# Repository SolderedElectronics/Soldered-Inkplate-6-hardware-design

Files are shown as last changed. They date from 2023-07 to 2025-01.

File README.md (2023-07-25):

# Inkplate 6 v2 Hardware design

## About the product

| Inkplate 6 v2 |
| :----------------------------------------------------------: |
|      [Buy Inkplate 6 v2](https://www.solde.red/333062)      |

If you’re like us, the first time you saw an e-reader, you thought to yourself, "I could do something with that." Thanks to clean lines, high contrast, daylight readability, and the remarkable level of energy efficiency that comes from drawing power only when changing the contents of the screen, e-paper is uniquely suited to many applications. With Inkplate 6, our goal is to make e-paper accessible to hobbyists and DIY product designers by offering a plug-and-play hardware platform that is super-easy to use and compatible with Arduino.

To name a few features, Inkplate 6 has stunning 6 inch e-paper display with refresh rate of 1.26s, with partial update 264ms, greyscale mode and partial updates support. Powered by ESP32, you will have strong microcontroller with WiFi and Bluetooth on your disposal. Using our Arduino library, it's 5 minute work to get the board running for you. It's 100% open-source for both software and hardware, so it's OSHWA certified. What is especially interesting is that Inkplate uses recycled screens taken from old e-book readers, which is very environmentally friendly, but you have to keep in mind that some screens may have small scratches because of this. All screens with large scratches and damages are not used at all.

## Repository contents

All Soldered Electronics hardware designed in KiCAD, and repositories are organized in the following way:

- CAD folder - contains KiCAD files (Schematics, Board, Panel Board), sorted by version. Change log lists all changes between versions.
- OUTPUTS - contains useful files, such as Bill of Materials (BOM), PDF of schematics, 3D .step file of the board and gerber files, sorted by version. 
- OUTPUTS -> Compliance - Certificates and useful legal stuff. 

## Want to contribute?

Please feel free to submit a pull request if you have any contributions. We encourage you to submit an issue or pull request if you find a bug. 

## About Soldered

soldered-logo

At Soldered, we design and manufacture a wide selection of electronic products to help you turn your ideas into acts and bring you one step closer to your final project. Our products are intented for makers and crafted in-house by our experienced team in Osijek, Croatia. We believe that sharing is a crucial element for improvement and innovation, and we work hard to stay connected with all our makers regardless of their skill or experience level. Therefore, all our products are open-source. Finally, we always have your back. If you face any problem concerning either your shopping experience or your electronics project, our team will help you deal with it, offering efficient customer service and cost-free technical support anytime. Some of those might be useful for you:

- [Web Store](https://www.soldered.com/shop)
- [Tutorials & Projects](https://soldered.com/learn)
- [Community & Technical support](https://soldered.com/community)

## License info

All Soldered open-source hardware (OSH) is under The TAPR Open Hardware License. Read more in the LICENSE file. 

No warranty - all designs in this repository are distributed in the hope that they will be useful, but without any warranty. They are provided "AS IS", therefore without warranty of any kind, either expressed or implied. The entire quality and performance of what you do with the contents of this repository are your responsibility. In no event, Soldered Electronics will be liable for your damages, losses, including any general, special, incidental or consequential damage arising out of the use or inability to use the contents of this repository. 

## Have fun! 
And thank you from your fellow makers at Soldered Electronics.

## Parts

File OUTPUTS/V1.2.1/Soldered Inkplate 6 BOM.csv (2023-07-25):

Id | Designator | Package | Quantity | Designation | Supplier and ref
1 | SW2 | YTSA007A0151803B | 1 | YTSA007A0151803B
2 | C34,C31,C49,C55,C27,C48,C33,C26,C44,C30,C36,C43,C38,C25,C56,C24,C42 | 0603C | 17 | 100n
3 | C23,C28,C47,C21,C37,C32 | 0603C | 6 | 2u2
4 | R20,R32,R8,R37,R38 | 0603R | 5 | 4k7
5 | L2 | NR4012 | 1 | NR4012T2R2M
6 | K9,K10,K47,K49,K21,K54,K29,K28,K6,K38,K34,K32,K56,K53,K27,K45,K24,K51,K33,K44,K30,K17,K31,K40,K57,K39,K19,K22,K41,K4,K37,K7,K42,K5,K55,K20,K35,K43,K25,K46,K36,K26,K58,K11,K18,K52,K12,K16,K48,K23,K50 | HEADER_MALE_1X1_Inkplate | 51 | HEADER_MALE_1X1_Inkplate
7 | F1 | 1206FUSE | 1 | 1206FUSE-500mA
8 | C6,C3,C4,C53,C54,C13,C12,C52,C2,C39,C51,C1,C9,C45,C11,C7 | 0805C | 16 | 4u7-TMK212AB7475KG-T
9 | R45,R4,R19,R33,R1,R22,R51 | 0603R | 7 | 10k
10 | D9,D6 | SOT-23-3 | 2 | BAT54S
11 | D1,D3 | SOD-323-2 | 2 | CUS10F30,H3F
12 | D10,D11 | M4_DIODA | 2 | M4_DIODA
13 | U6 | SOT-23-5 | 1 | TPS3840PL27DBVR
14 | U3 | TPS7A2633DRVR | 1 | TPS7A2633DRVR
15 | PAD2,PAD5,PAD6,PAD7,PAD1,PAD4,PAD3 | PAD_4x4 | 7 | PAD_4x4
16 | X1 | ABS07AIG-32.768KHZ-7-D-T | 1 | 7LC32768F12UC
17 | R16,R25,R5,R17,R43,R26,R6,R47,R7,R44,R49,R48,R31,R15 | 0603R | 14 | 100k
18 | L1 | 1515L | 1 | LQH44PN4R7MP0L
19 | R10 | 0603R | 1 | 2k49
20 | SW1,SW3 | K2-1114SA-A4SW-06 | 2 | K2-1114SA-A4SW-06
21 | U10 | PCF85063A | 1 | PCF85063A
22 | R50 | 0603R | 1 | 330R
23 | R36,R35,R14,R21,R23,R27,R24,R9,R34 | 0603R | 9 | 1k
24 | U12 | ESP32-WROVER | 1 | ESP32-WROVER
25 | K1 | INKPLATE TEST HEADER | 1 | Inkplate_TP
26 | C8,C5,C10 | 0603C | 3 | 10u-GRM188R61E106KA73J
27 | C20,C50 | 2917C | 2 | DNP
28 | R29,R18 | 0603R | 2 | DNP
29 | C41,C40 | 0603C | 2 | DNP
30 | Q10,Q1,Q2 | SOT-23-3 | 3 | PMOS
31 | D2,D12,D5,D4 | SOD-323 | 4 | BAT20J
32 | D7 | 0402LED | 1 | RED
33 | R11 | 0603R | 1 | 510k
34 | U8,U9 | PCAL6416AHF,128 | 2 | PCAL6416AHF,128
35 | Q7,Q5,Q6 | SOT-23-3 | 3 | NPN
36 | C14,C15 | 0603C | 2 | 2u2-GRM188R61E225MA12D
37 | K13 | HYC77-TF09-200 | 1 | HYC77-TF09-200
38 | JP3,JP6,JP4,JP2,JP5 | SMD_JUMPER_3_PAD_CONNECTED_LEFT_TRACE | 5 | SMD_JUMPER_3_PAD_CONNECTED_LEFT_TRACE
39 | K14 | CR2032-BS-6-1 | 1 | CR2032_BS-6-1
40 | R13,R12 | 0603R | 2 | 5k1
41 | C17,C16 | 0603C | 2 | 10n-AC0603KRX7R8BB103
42 | H1,H4,H3,H2 | Standoff_M3 | 4 | Standoff_M3
43 | K8 | easyC-connector | 1 | easyC-SMD
44 | U1 | VQFN-49 | 1 | TPS65186RGZ
45 | D8 | LTST-S270GKT | 1 | 0603LED_SIDE
46 | K15 | AXT334124 | 1 | AXT334124
47 | Q3 | SOT-23-3 | 1 | NMOS
48 | R41,R39 | 0603R | 2 | 1M
49 | C35 | 0603C | 1 | 100p
50 | R2 | 0603R | 1 | NTC-NCP18XH103F03RB
51 | R28 | 0603R | 1 | 0R
52 | JP1 | SMD_JUMPER | 1 | SMD_JUMPER
53 | C46,C22,C29 | 1206C | 3 | 10u
54 | S1 | SK-3296S-01-L1 | 1 | SK-3296S-01-L1
55 | K2 | JST-2pin-SMD | 1 | JST-2pin-SMD
56 | R40 | 0603R | 1 | 47k5-RC0603FR-0747K5L
57 | R3 | 0603R | 1 | 43k-RC0603FR-0743KL
58 | C19,C18 | 0603C | 2 | 100n-AC0603KRX7R8BB104
59 | R46 | 0603R | 1 | 47k
60 | U5 | SOP-16 | 1 | CH340C
61 | R42 | 0603R | 1 | 52k3-RC0603FR-0752K3L
62 | R30 | 0603R | 1 | 47R
63 | Q9 | SOT-23-3 | 1 | DNP
64 | Q8,Q4 | SOT-23-3 | 2 | SSM3J358R,LF
65 | U2 | SOT-23-5 | 1 | MCP73831T
66 | U7 | SN74LVC1G34DBV | 1 | SN74LVC1G34DBV
67 | U4 | TSSOP-14 | 1 | MC14093BDTR2G
68 | K3 | U262-161N-4BVC11 | 1 | U262-161N-4BVC11
69 | U11 | ED060SC7 | 1 | ED060SC7

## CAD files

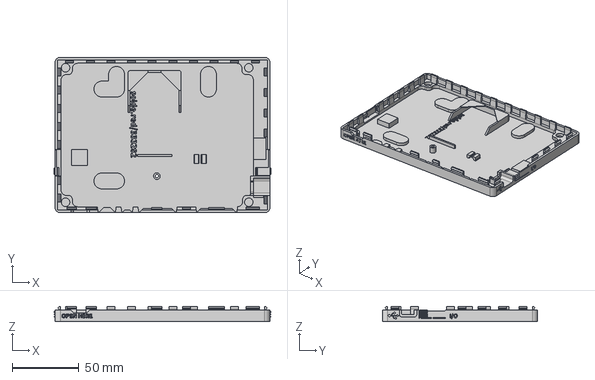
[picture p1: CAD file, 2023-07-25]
CAD/V1.2.1/Source 3D files/Soldered Inkplate 6 v1.2.0. Bottom v1.1.2..step
163.0 x 116.8 x 11.3 mm

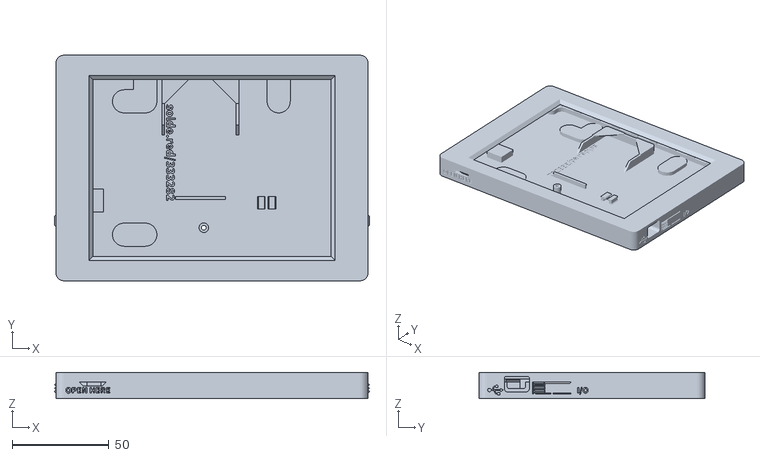
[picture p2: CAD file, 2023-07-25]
OUTPUTS/V1.2.1/3D printable files/Soldered Inkplate 6 v1.2.0. Case.stl
163.0 x 116.8 x 13.5

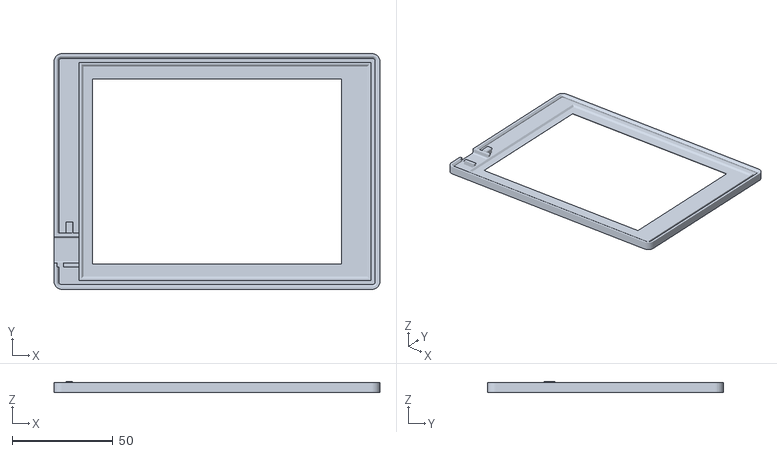
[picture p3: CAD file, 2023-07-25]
OUTPUTS/V1.2.1/3D printable files/Soldered Inkplate 6 v1.2.0. Top v 1.1.2..stl
161.4 x 116.8 x 5.60

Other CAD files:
CAD/V1.2.1/Source 3D files/Soldered Inkplate 6 v1.2.0. Case.step
CAD/V1.2.1/Source 3D files/Soldered Inkplate 6 v1.2.0. Top v 1.1.2..step
OUTPUTS/V1.2.1/3D printable files/Soldered Inkplate 6 v1.2.0. Bottom v1.1.2..stl
CAD/V1.2.0/Source 3D files/Soldered Inkplate 6 v1.2.0. Top v 1.1.2..step
CAD/V1.2.0/Source 3D files/Soldered Inkplate 6 v1.2.0. Case.step
OUTPUTS/V1.2.0/3D printable files/Soldered Inkplate 6 v1.2.0. Bottom v1.1.2..stl
CAD/V1.2.0/Source 3D files/Soldered Inkplate 6 v1.2.0. Bottom v1.1.2..f3d
CAD/V1.2.0/Source 3D files/Soldered Inkplate 6 v1.2.0. Case.f3z
CAD/V1.2.0/Source 3D files/Soldered Inkplate 6 v1.2.0. Top v 1.1.2..f3d
CAD/V1.2.1/Source 3D files/Soldered Inkplate 6 v1.2.0. Bottom v1.1.2..f3d
CAD/V1.2.1/Source 3D files/Soldered Inkplate 6 v1.2.0. Case.f3z
CAD/V1.2.1/Source 3D files/Soldered Inkplate 6 v1.2.0. Top v 1.1.2..f3d

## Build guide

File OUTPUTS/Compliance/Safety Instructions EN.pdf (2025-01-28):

PLEASE RETAIN THIS INFORMATION FOR FUTURE REFERENCE.

BEFORE USING THIS PRODUCT, READ ALL INSTRUCTION IN THIS DOCUMENT.

Product name: Soldered Inkplate 6
Getting started: To get started, please visit www.soldered.com

## WARNINGS

- This product should not be covered and should be operated in well ventilated enviroment.
- The product should be placed on a stable, flat, non-conductive surface and should not be contacted by conductive items.
- Connection of other devices may affect compliance or result in damage to the unit, and invalidate the warranty.
- Where peripherals are connected that do not include the cable or connector, the cable or connector used must offer adequate insulation and operation in order that the requirements of the relevant performance and safety requirements are met.
- There is a danger of explosion if the battery is incorrectly placed.
- The product should not be used outside of its specified working range.

## INSTRUCTIONS FOR SAFE USE

To avoid malfunction or damage to your device, please observe the following:
- Do not expose it to water, moisture or place on a conductive surface when turned on. Do not handle the unit with wet hands.
- Do not expose it to heat from any source; the product is designed to be used at normal ambient room temperatures. The product is intended to be used inside.
- Take care when handling to avoid mechanical or electrical damage to any part of the unit. Avoid handling the unit while it's powered. Use ESD protection.
- Use only supplied cable (or the cable of the same or higher quality) with the unit.

## COMPLIANCE INFORMATION

The product complies with the relevant provision of the RoHS Directive for the European Union. In common with all Electrical and Electronic Equipment (EEE), the product should not be disposed household waste.

ELECTROMAGNETIC COMPABILITY AND OPERATION

- The product is in conformity with the protection requirements of EU Council Directive 2014/30/EU on the laws of the Member States relating of electromagnetic compability, and Electromagnetic Compability Regulations 2016 of the UK.
- WARNING: Please do not alter the design of this product, doing so may void your ability to use the product freely, this includes altering the frequency at which product operates.

### Regulatory Compliance and Important Safety Information

Soldered Electronics d.o.o., Vinkovačka cesta 68, 31000 Osijek, Croatia. VAT ID: HR83200237288

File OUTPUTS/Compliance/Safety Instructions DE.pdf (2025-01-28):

BITTE BEWAHREN SIE DIESE INFORMATIONEN ZUR SPÄTEREN VERWENDUNG AUF.
LESEN SIE VOR DER VERWENDUNG DIESES PRODUKTS ALLE ANWEISUNGEN IN DOKUMENT. Produktname: Soldered Inkplate 6
Die ersten Schritte:Besuchen Sie www.soldered.com, um loszulegen.

## WARNUNGEN

- Dieses Produkt sollte nicht abgedeckt werden und in einer gut belüfteten Umgebung betrieben werden.
- Das Produkt sollte auf einer stabilen, flachen, nicht leitenden Oberfläche aufgestellt werden und nicht mit leitenden Gegenständen in Berührung kommen.
- Der Anschluss anderer Geräte kann die Konformität beeinträchtigen oder zu Schäden am Gerät führen und zum Erlöschen der Garantie führen.
- Wenn Peripheriegeräte angeschlossen werden, die nicht das Kabel oder den Stecker enthalten, muss das verwendete Kabel oder muss das verwendete Kabel bzw. der verwendete Steckverbinder eine angemessene Isolierung und Funktion aufweisen, damit die Anforderungen die einschlägigen Leistungs- und Sicherheitsanforderungen erfüllt werden.
- Es besteht Explosionsgefahr, wenn die Batterie falsch eingesetzt wird.
- Das Produkt sollte nicht außerhalb des angegebenen Arbeitsbereichs verwendet werden.

## HINWEISE ZUR SICHEREN ANWENDUNG

Um Fehlfunktionen oder Schäden an Ihrem Gerät zu vermeiden, beachten Sie bitte die folgenden Hinweise:
- Setzen Sie das Gerät nicht Wasser oder Feuchtigkeit aus und stellen Sie es nicht auf eine
leitende Oberfläche, wenn es eingeschaltet ist. Das Gerät nicht mit nassen Händen anfassen.
- Setzen Sie es keiner Wärmequelle aus; das Produkt ist für die Verwendung bei normalen Raumtemperaturen ausgelegt. Das Produkt ist für die Verwendung in Innenräumen vorgesehen.
- Seien Sie bei der Handhabung vorsichtig, um mechanische oder elektrische Schäden an Teilen des Geräts zu vermeiden. Fassen Sie das Gerät nicht an, wenn es unter Spannung steht. Verwenden Sie einen ESD-Schutz.
- Verwenden Sie nur das mitgelieferte Kabel (oder ein gleich- oder höherwertiges Kabel)
mit dem Gerät.

## COMPLIANCE-INFORMATIONEN

Das Produkt entspricht den entsprechenden Bestimmungen der RoHS-Richtlinie für die Europäische Union. Wie alle elektrischen und elektronischen Geräte (EEE), sollte das Produkt nicht über den Hausmüll entsorgt werden.
ELEKTROMAGNETISCHE VERTRÄGLICHKEIT UND BETRIEB
- Das Produkt entspricht den Schutzanforderungen der Richtlinie des EU-Rates 2014/30/EU über die Rechtsvorschriften der Mitgliedstaaten zur elektromagnetischen Verträglichkeit und den Elektromagnetische Verträglichkeitsverordnung 2016 des Vereinigten Königreichs.
- WARNUNG: Bitte verändern Sie nicht das Design dieses Produkts, da dies dazu führen kann, dass Sie das Produkt nicht mehr uneingeschränkt nutzen können.
Dies gilt auch für die Änderung der Frequenz, mit der das Produkt arbeitet.

## Einhaltung gesetzlicher Vorschriften und wichtige

Soldered Electronics d.o.o., Vinkovačka cesta 68, 31000 Osijek, Croatia. VAT ID: HR83200237288

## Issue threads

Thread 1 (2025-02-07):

Supported Inkplate 6 Versions

itopaloglu83, 2025-02-07:
Hello,

It looks like there are multiple versions of Soldered Inkplate 6. The product link on the readme file points to the retired version. And the inkplate documentation points to another repo with different files. Which versions does this repo support? Also is there a way to determine which exact version we have (v1.2.0 vs v1.2.1)? Thank you.

https://soldered.com/product/inkplate-6-6-e-paper-board/ (SKU: 333232)

https://soldered.com/product/retired-inkplate-6-6-e-paper-board/ (SKU: 333062)
https://github.com/SolderedElectronics/Inkplate-6-hardware (inkplate documentation)

Edit: The SKU number engraved on the STL files says "solde.red/333282".

rsoric, 2025-02-18:
Greetings @itopaloglu83,

sorry for a bit of a late reply, we were busy with some projects.

The e-radionica Inkplates are the older versions (mostly blue PCB) and purple Inkplates are Soldered Inkplates (purple PCB). This difference also has to do with the different GPIO expander on board, check out this page in our documentation: https://inkplate.readthedocs.io/en/latest/arduino.html#io-expander-functions

The retired product you linked is the e-radionica Inkplate 6 (it also has touchpads, this is how I know, the newer version doesn't have those), the non-retired one is the Soldered version. This repository is for the Soldered (non-retired) version.

The battery which fits perfectly in the case is the SKU engraved in the STL, and this is the battery which we ship in the version of our device with battery.

Hope that's useful, all the best
-Rob

Closed 2025-02-18.

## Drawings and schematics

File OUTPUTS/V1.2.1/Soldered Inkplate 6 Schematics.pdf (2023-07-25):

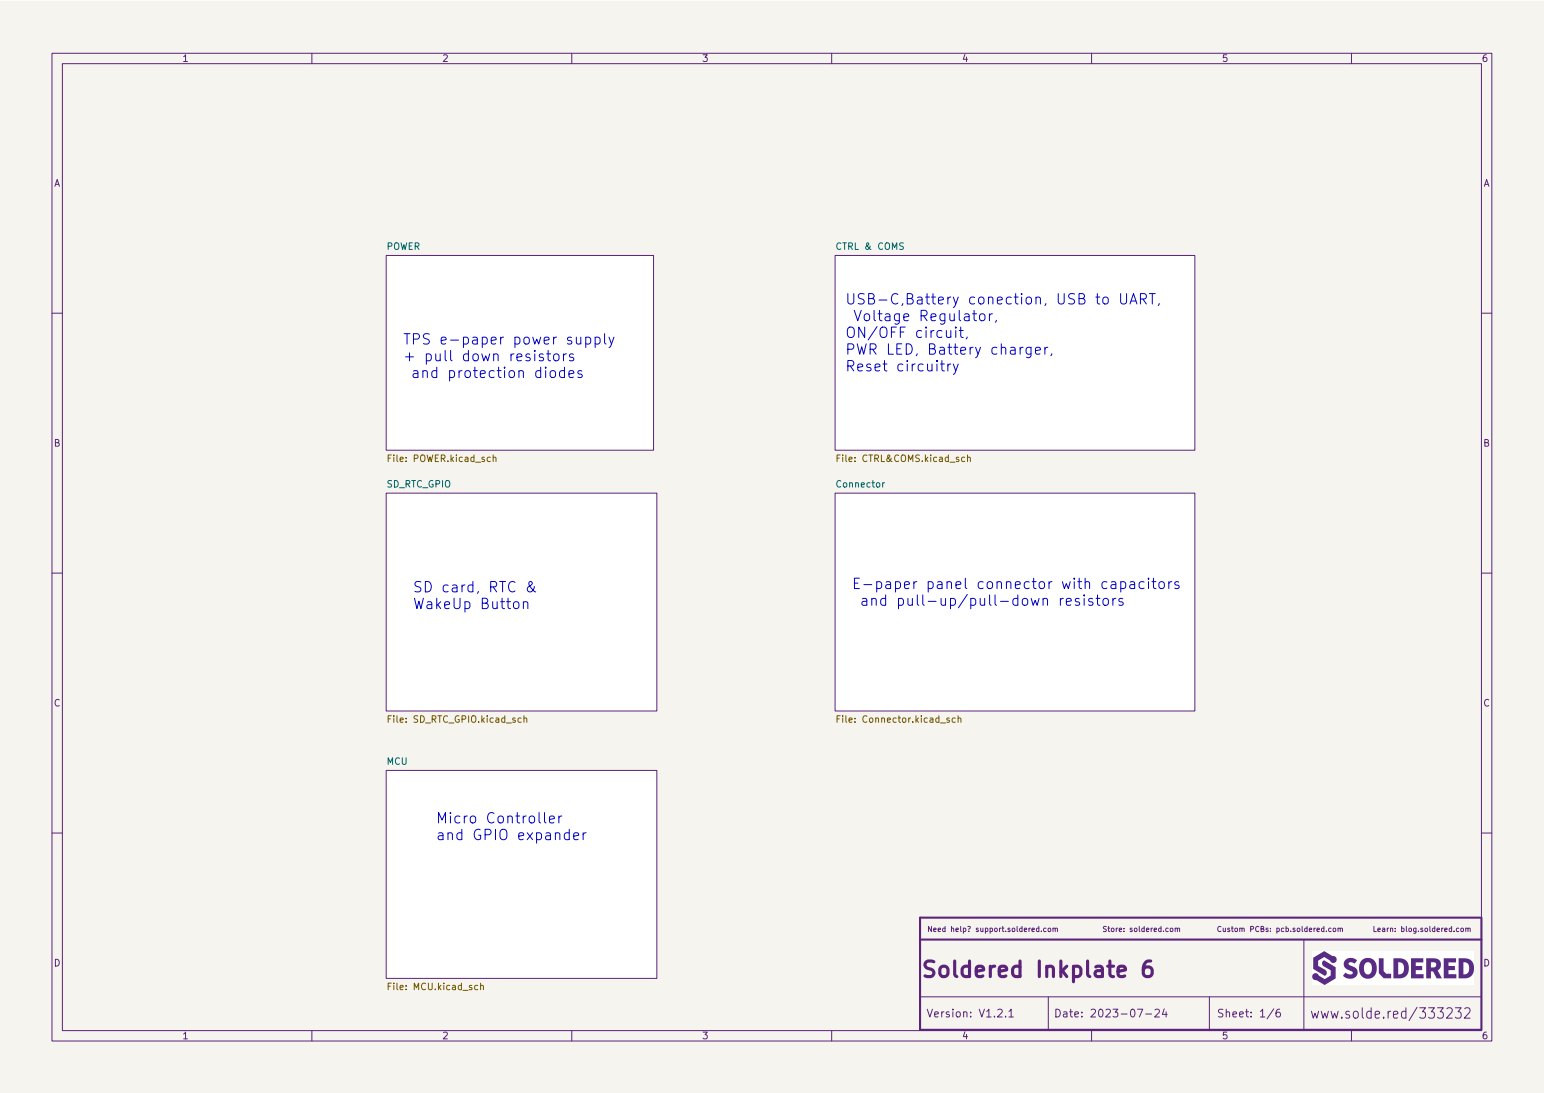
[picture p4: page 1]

Voltage Regulator,
ON/OFF circuit,
PWR LED, Battery charger,
Reset circuitry

TPS e-paper power supply
+ pull down resistors
and protection diodes

File: CTRL&COMS.kicad_sch Connector File: Connector.kicad_sch SD_RTC_GPIO

E-paper panel connector with capacitors
and pull-up/pull-down resistors

Learn: blog.soldered.com

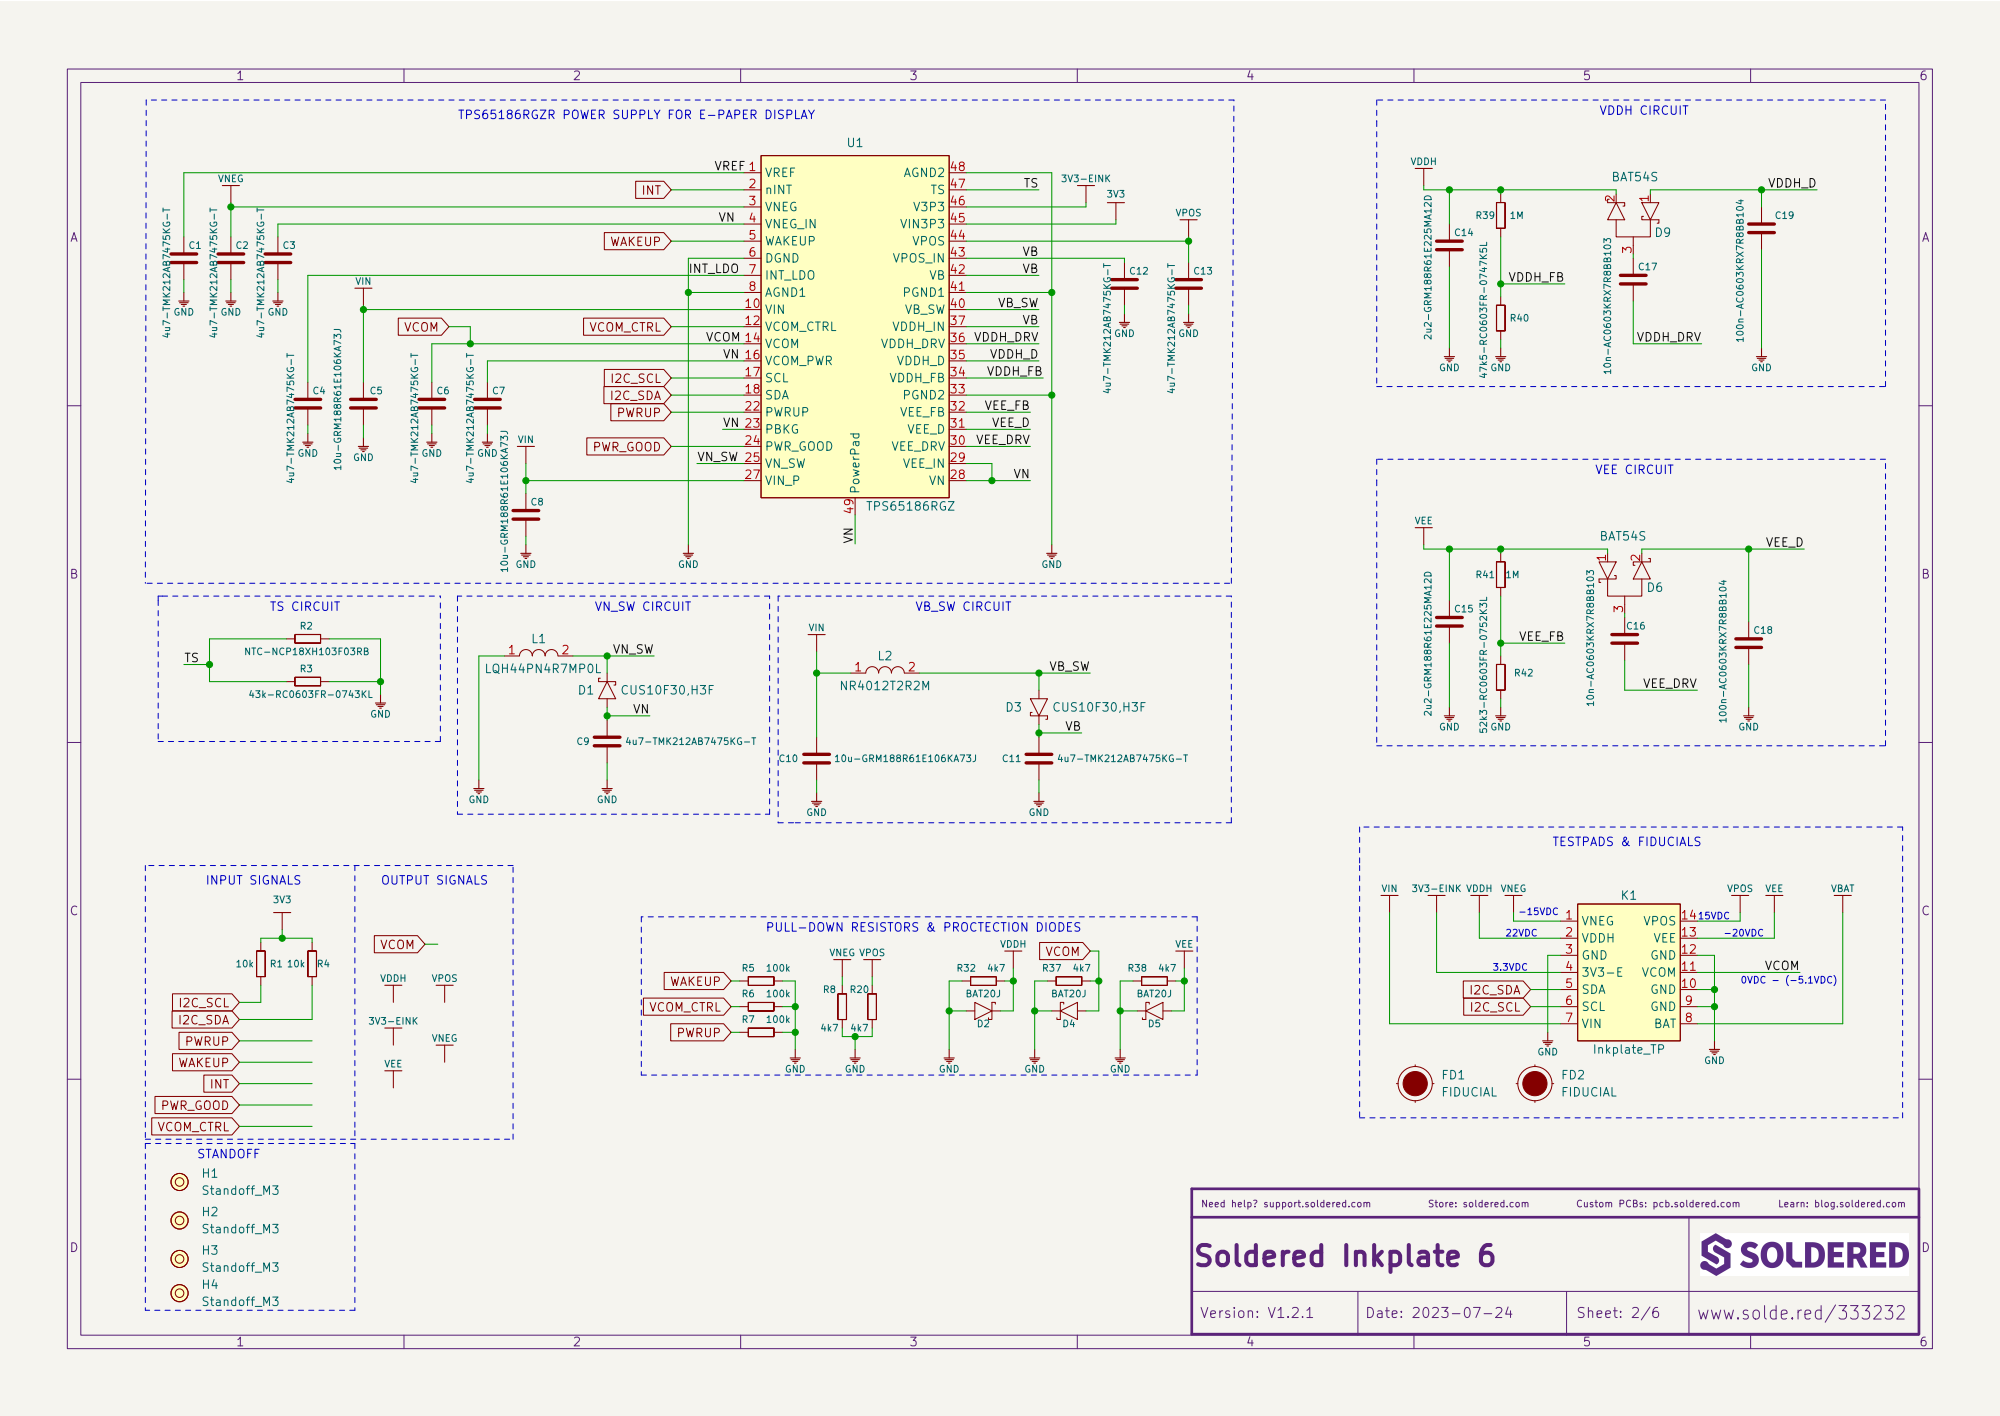
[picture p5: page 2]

TPS65186RGZR POWER SUPPLY FOR E-PAPER DISPLAY

VREF 1 VIN 10 VCOM_CTRL 12 VCOM 14 VCOM_PWR 16 SCL 17 SDA 18

VN | VDDH_D
VN VN_SW | VDDH_FB

0VDC - (-5.1VDC) PULL-DOWN RESISTORS & PROCTECTION DIODES OUTPUT SIGNALS

Learn: blog.soldered.com

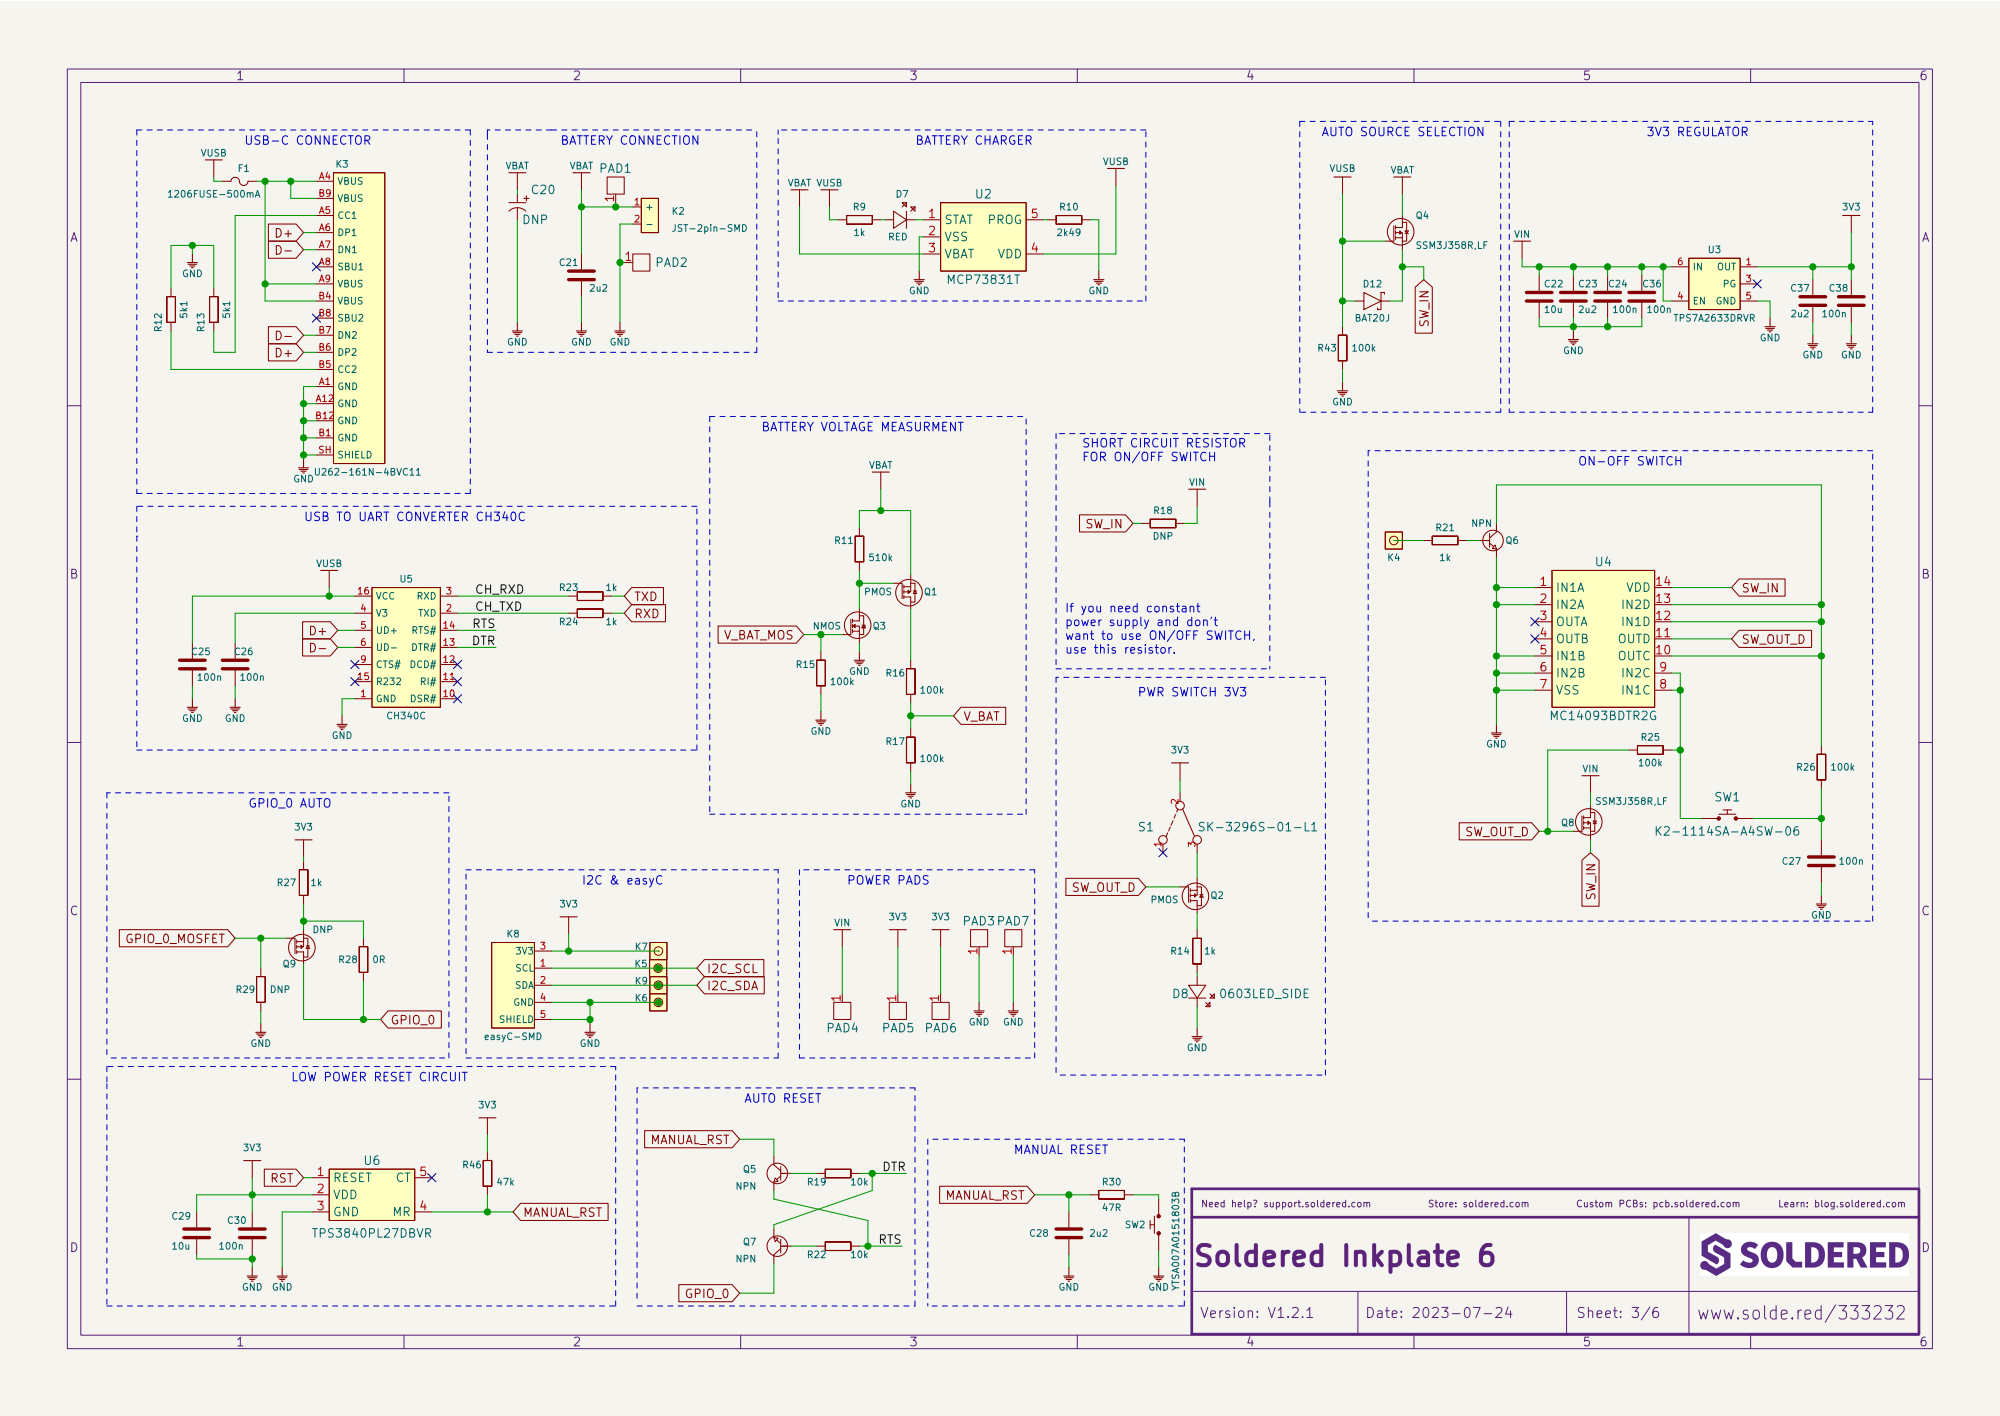
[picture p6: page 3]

BATTERY VOLTAGE MEASURMENT POWER PADS

power supply and don't want to use ON/OFF SWITCH, use this resistor. PWR SWITCH 3V3 SHORT CIRCUIT RESISTOR
FOR ON/OFF SWITCH

USB TO UART CONVERTER CH340C

If you need constant

1 PAD5 Q7 NPNQ5 NPN RESET R19 10k 1 VDD 2 GND 3 MR 4 CT 5 U6 TPS3840PL27DBVR
100n GND

LOW POWER RESET CIRCUIT

Learn: blog.soldered.com

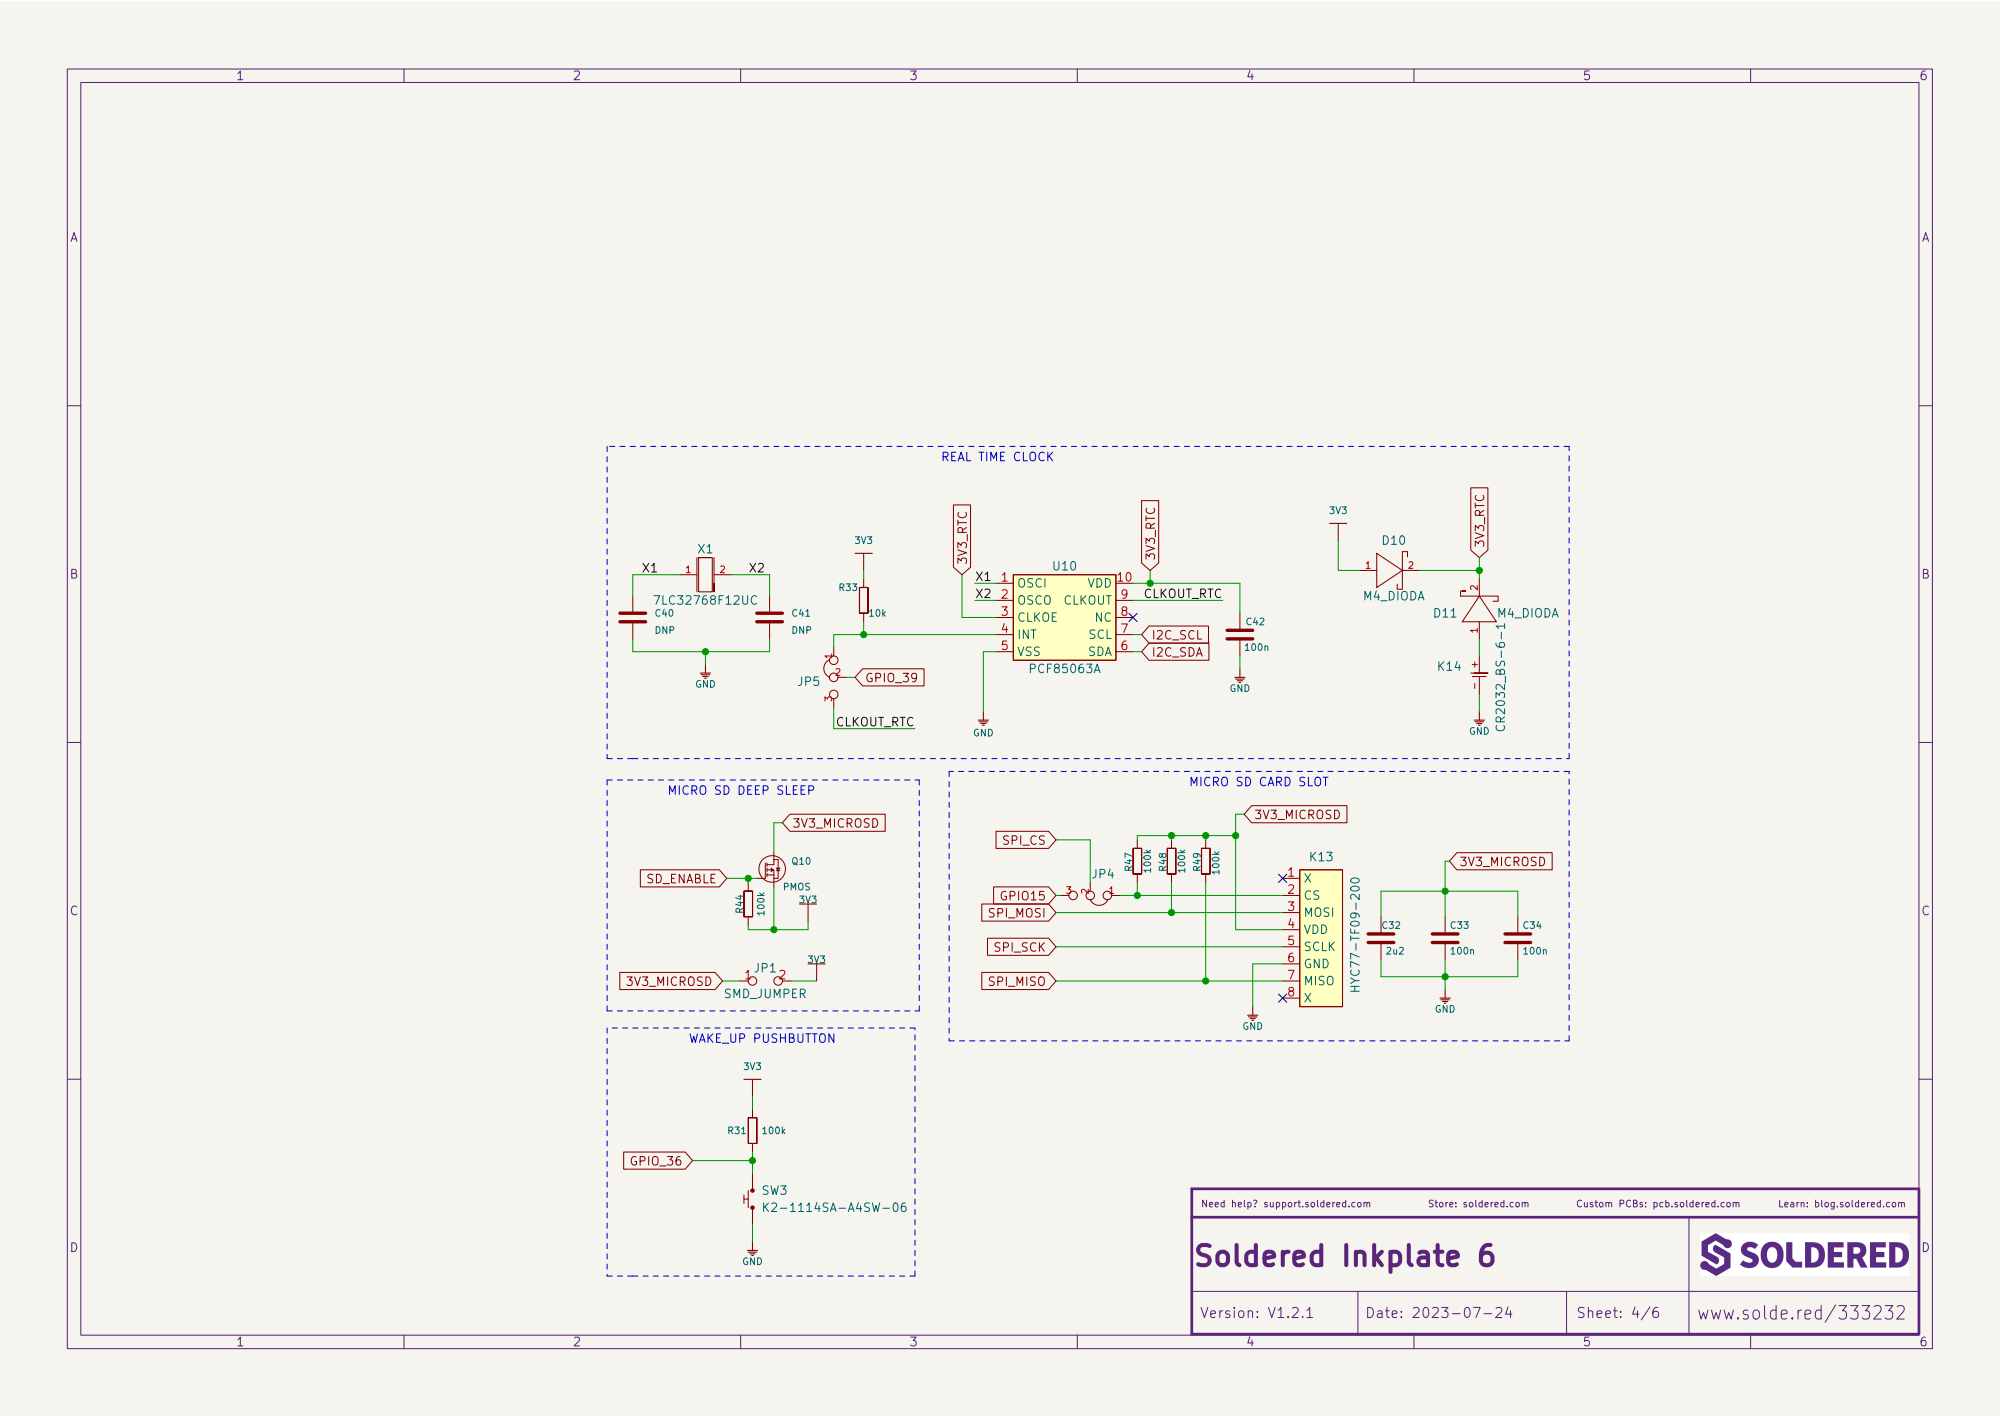
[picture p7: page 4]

Learn: blog.soldered.com

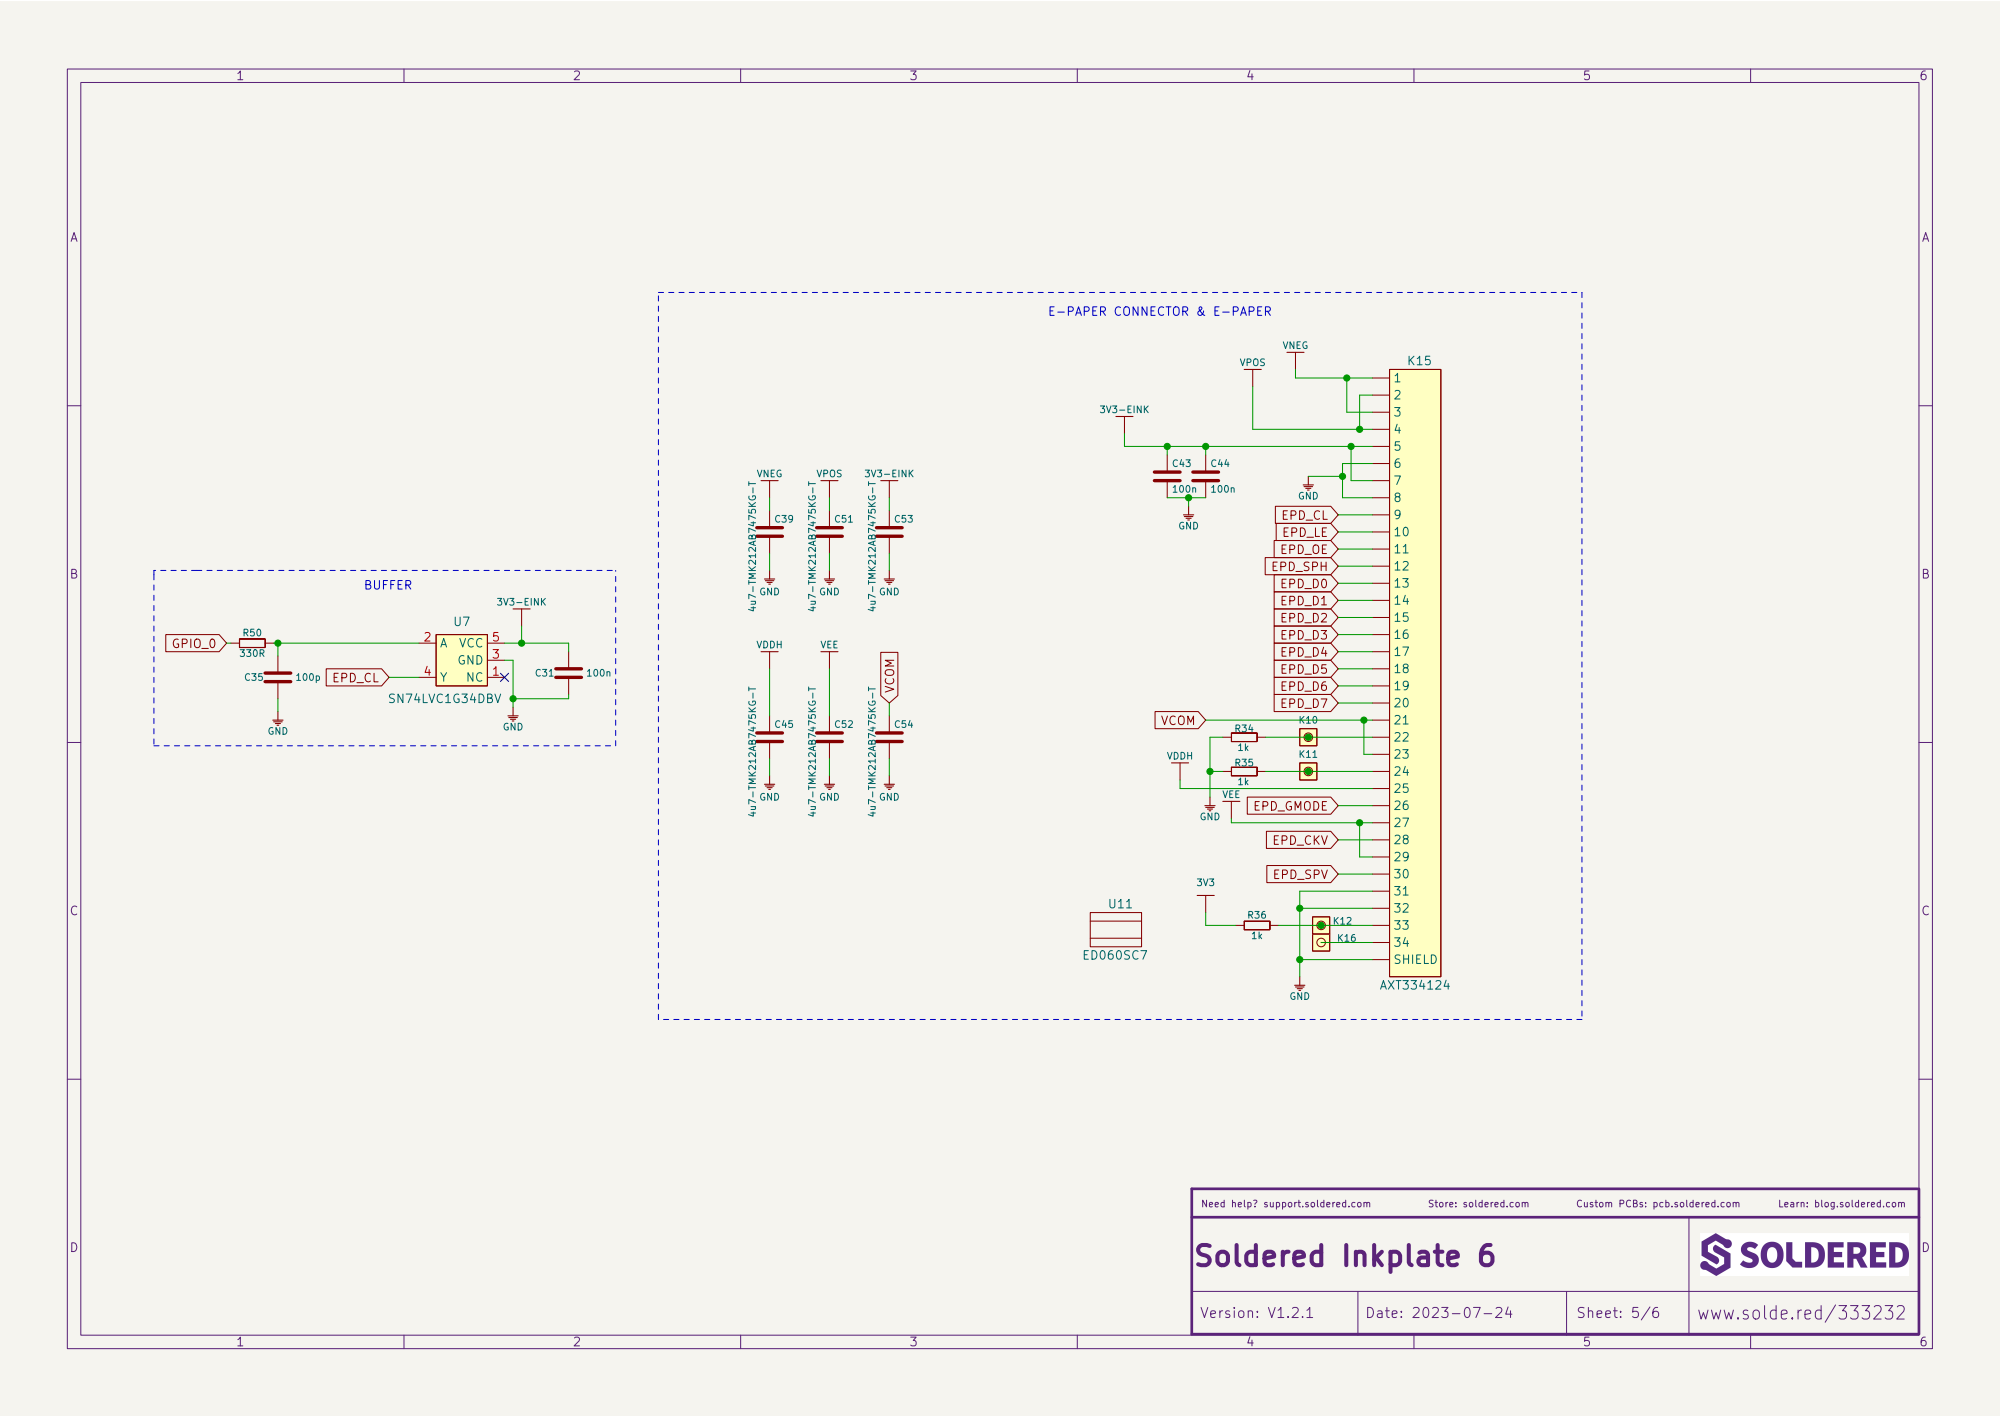
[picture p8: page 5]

Learn: blog.soldered.com

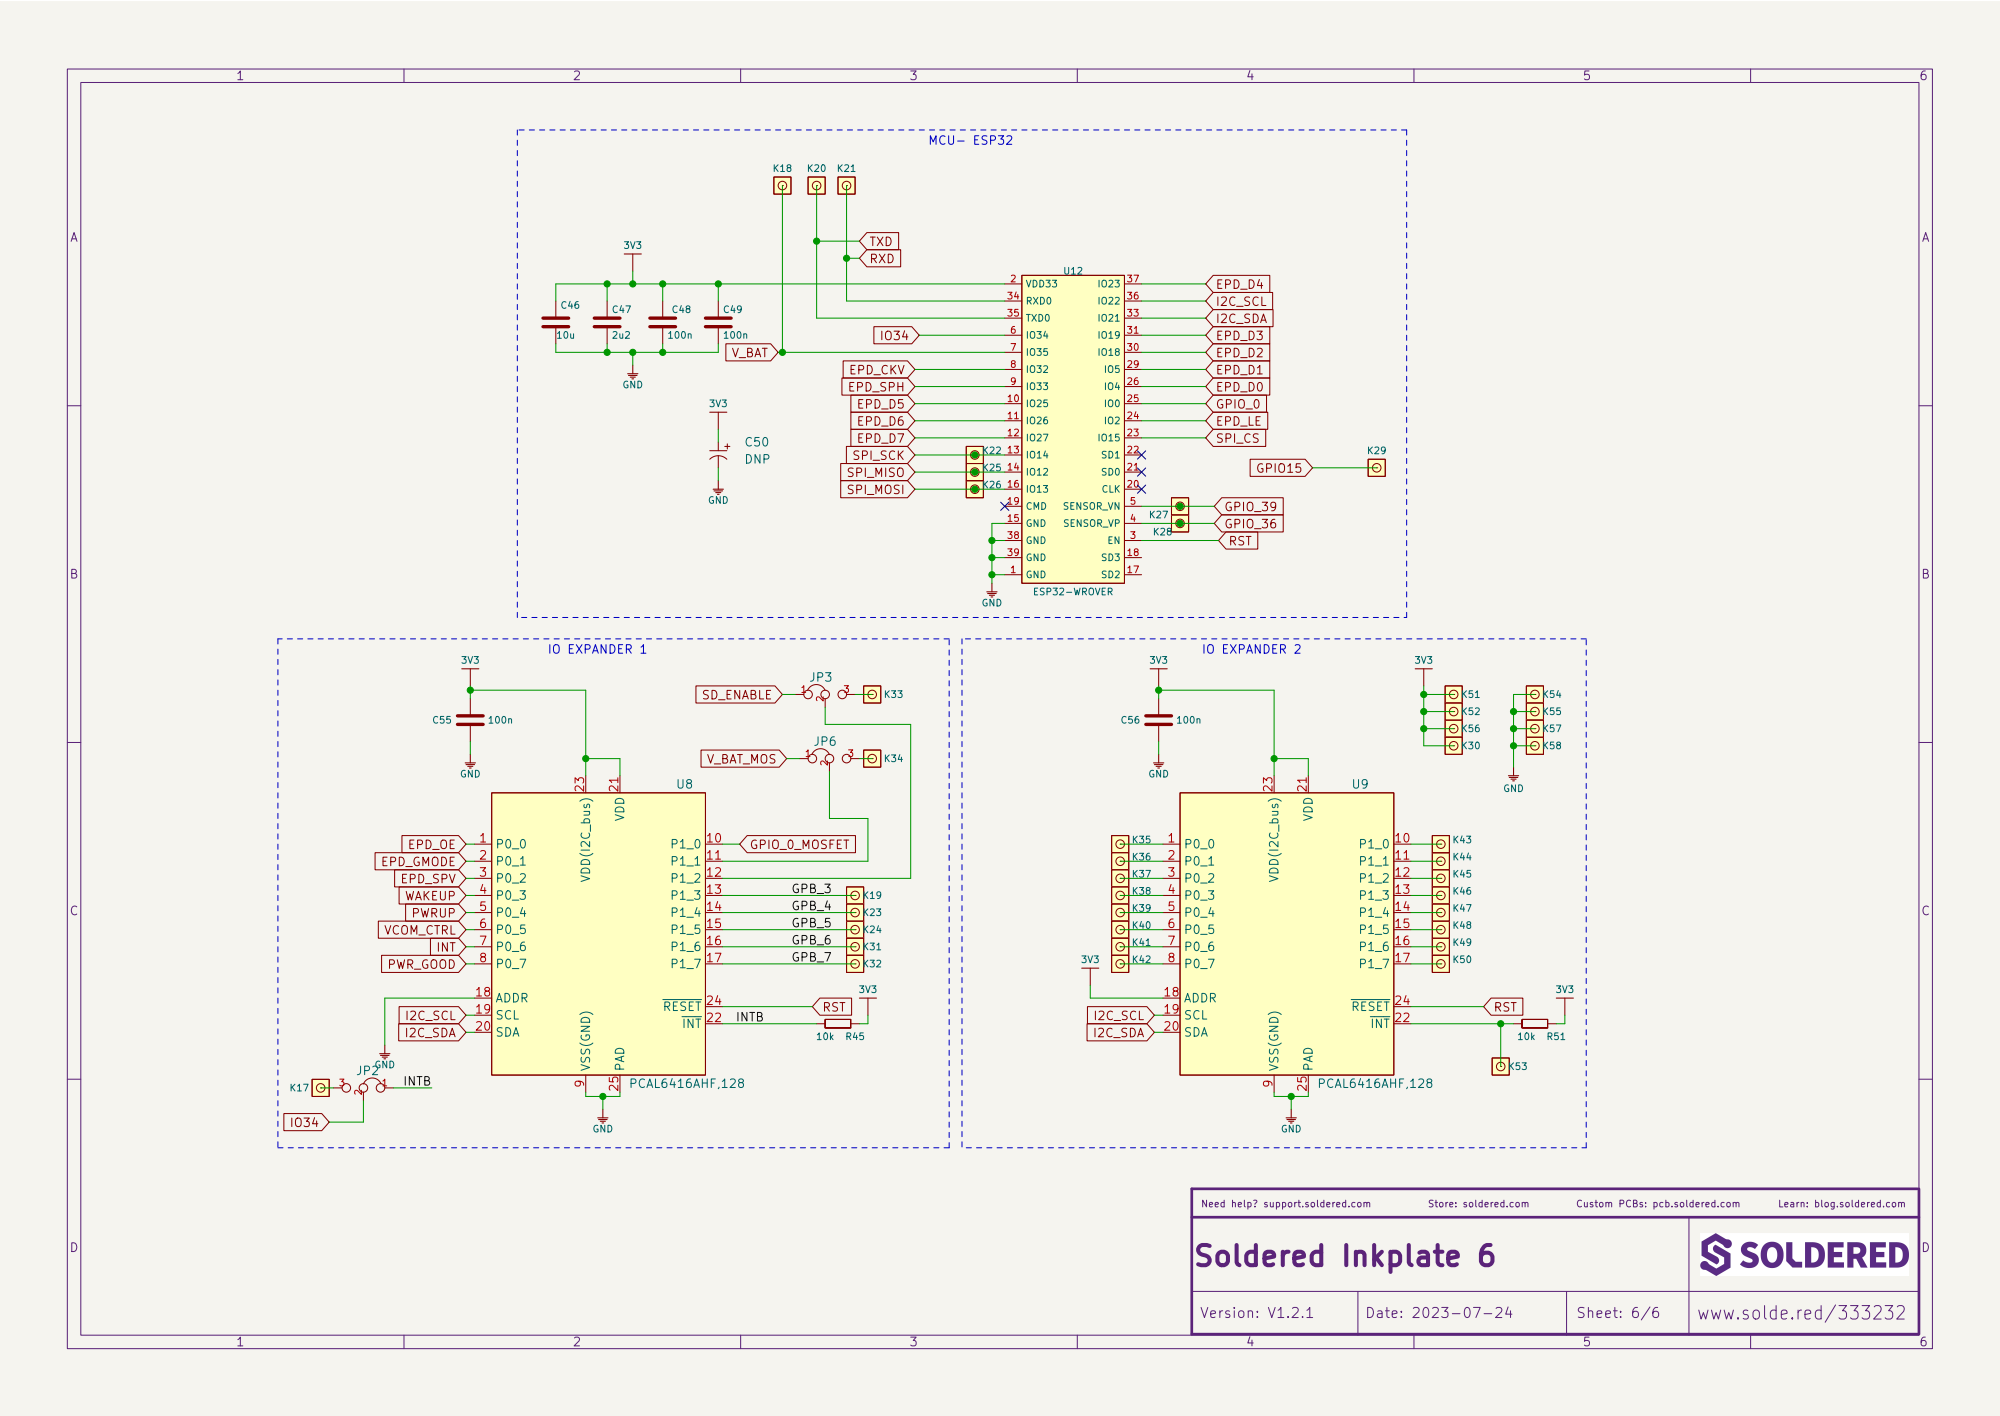
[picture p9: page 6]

Learn: blog.soldered.com

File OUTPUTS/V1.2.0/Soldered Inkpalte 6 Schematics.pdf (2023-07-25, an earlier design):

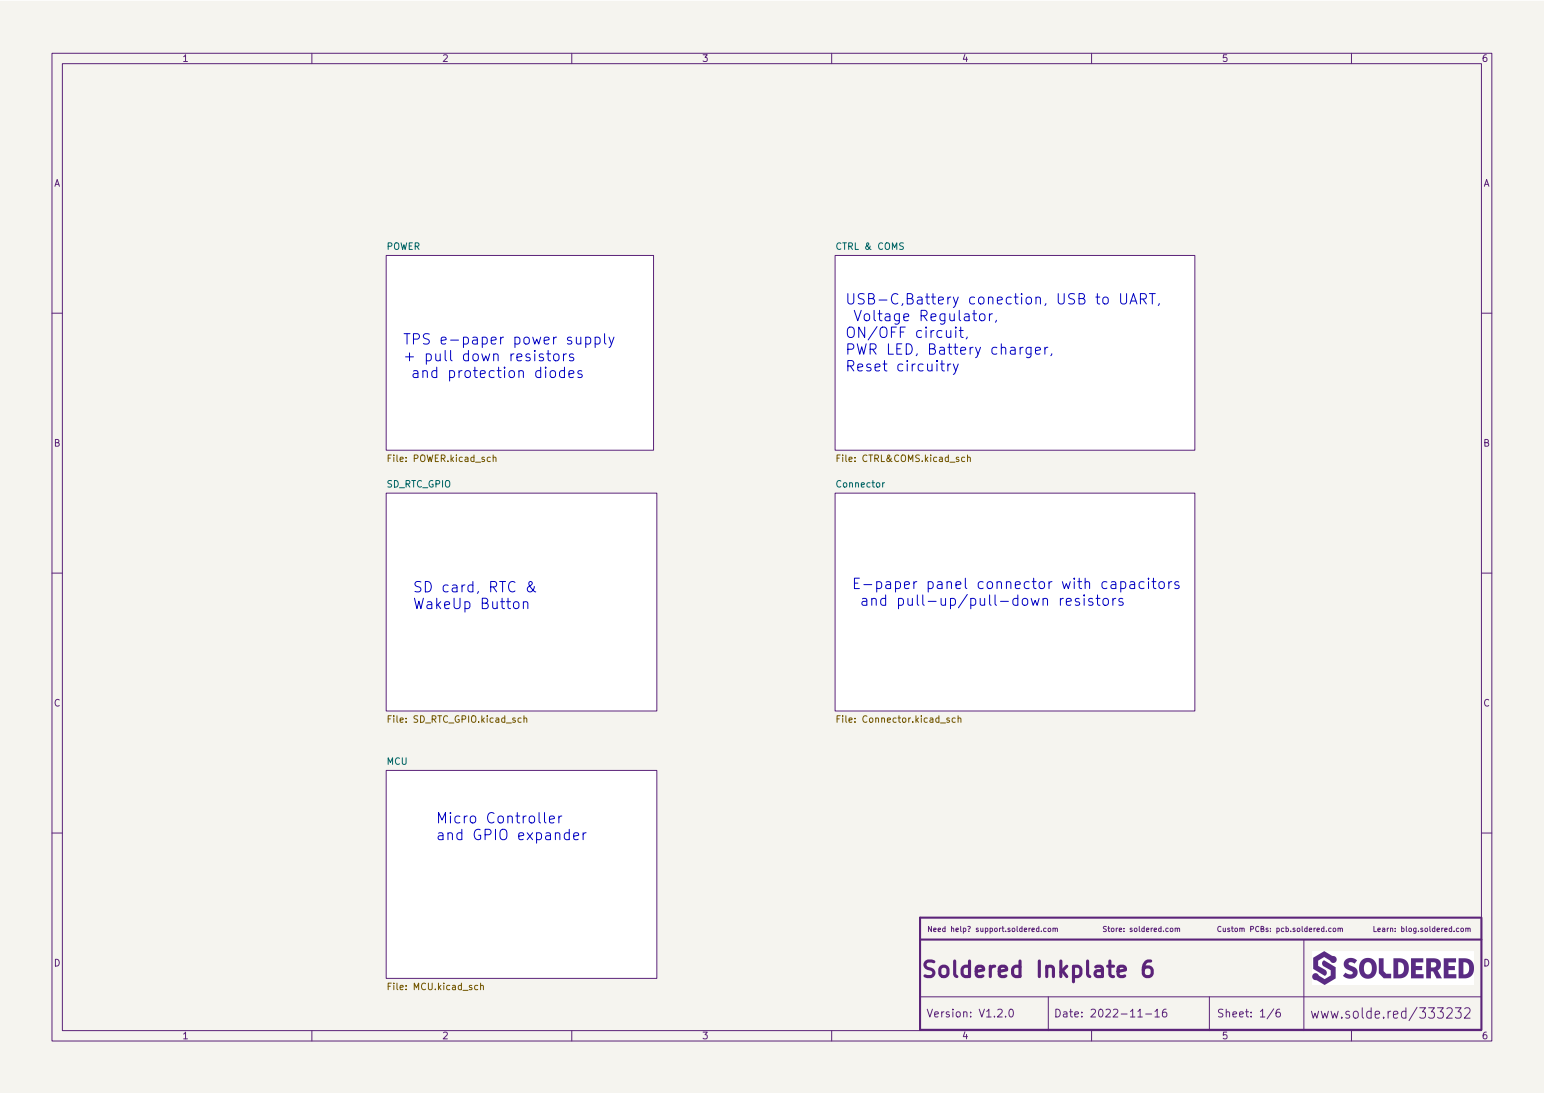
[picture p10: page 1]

Voltage Regulator,
ON/OFF circuit,
PWR LED, Battery charger,
Reset circuitry

TPS e-paper power supply
+ pull down resistors
and protection diodes

File: CTRL&COMS.kicad_sch Connector File: Connector.kicad_sch SD_RTC_GPIO

E-paper panel connector with capacitors
and pull-up/pull-down resistors

Learn: blog.soldered.com

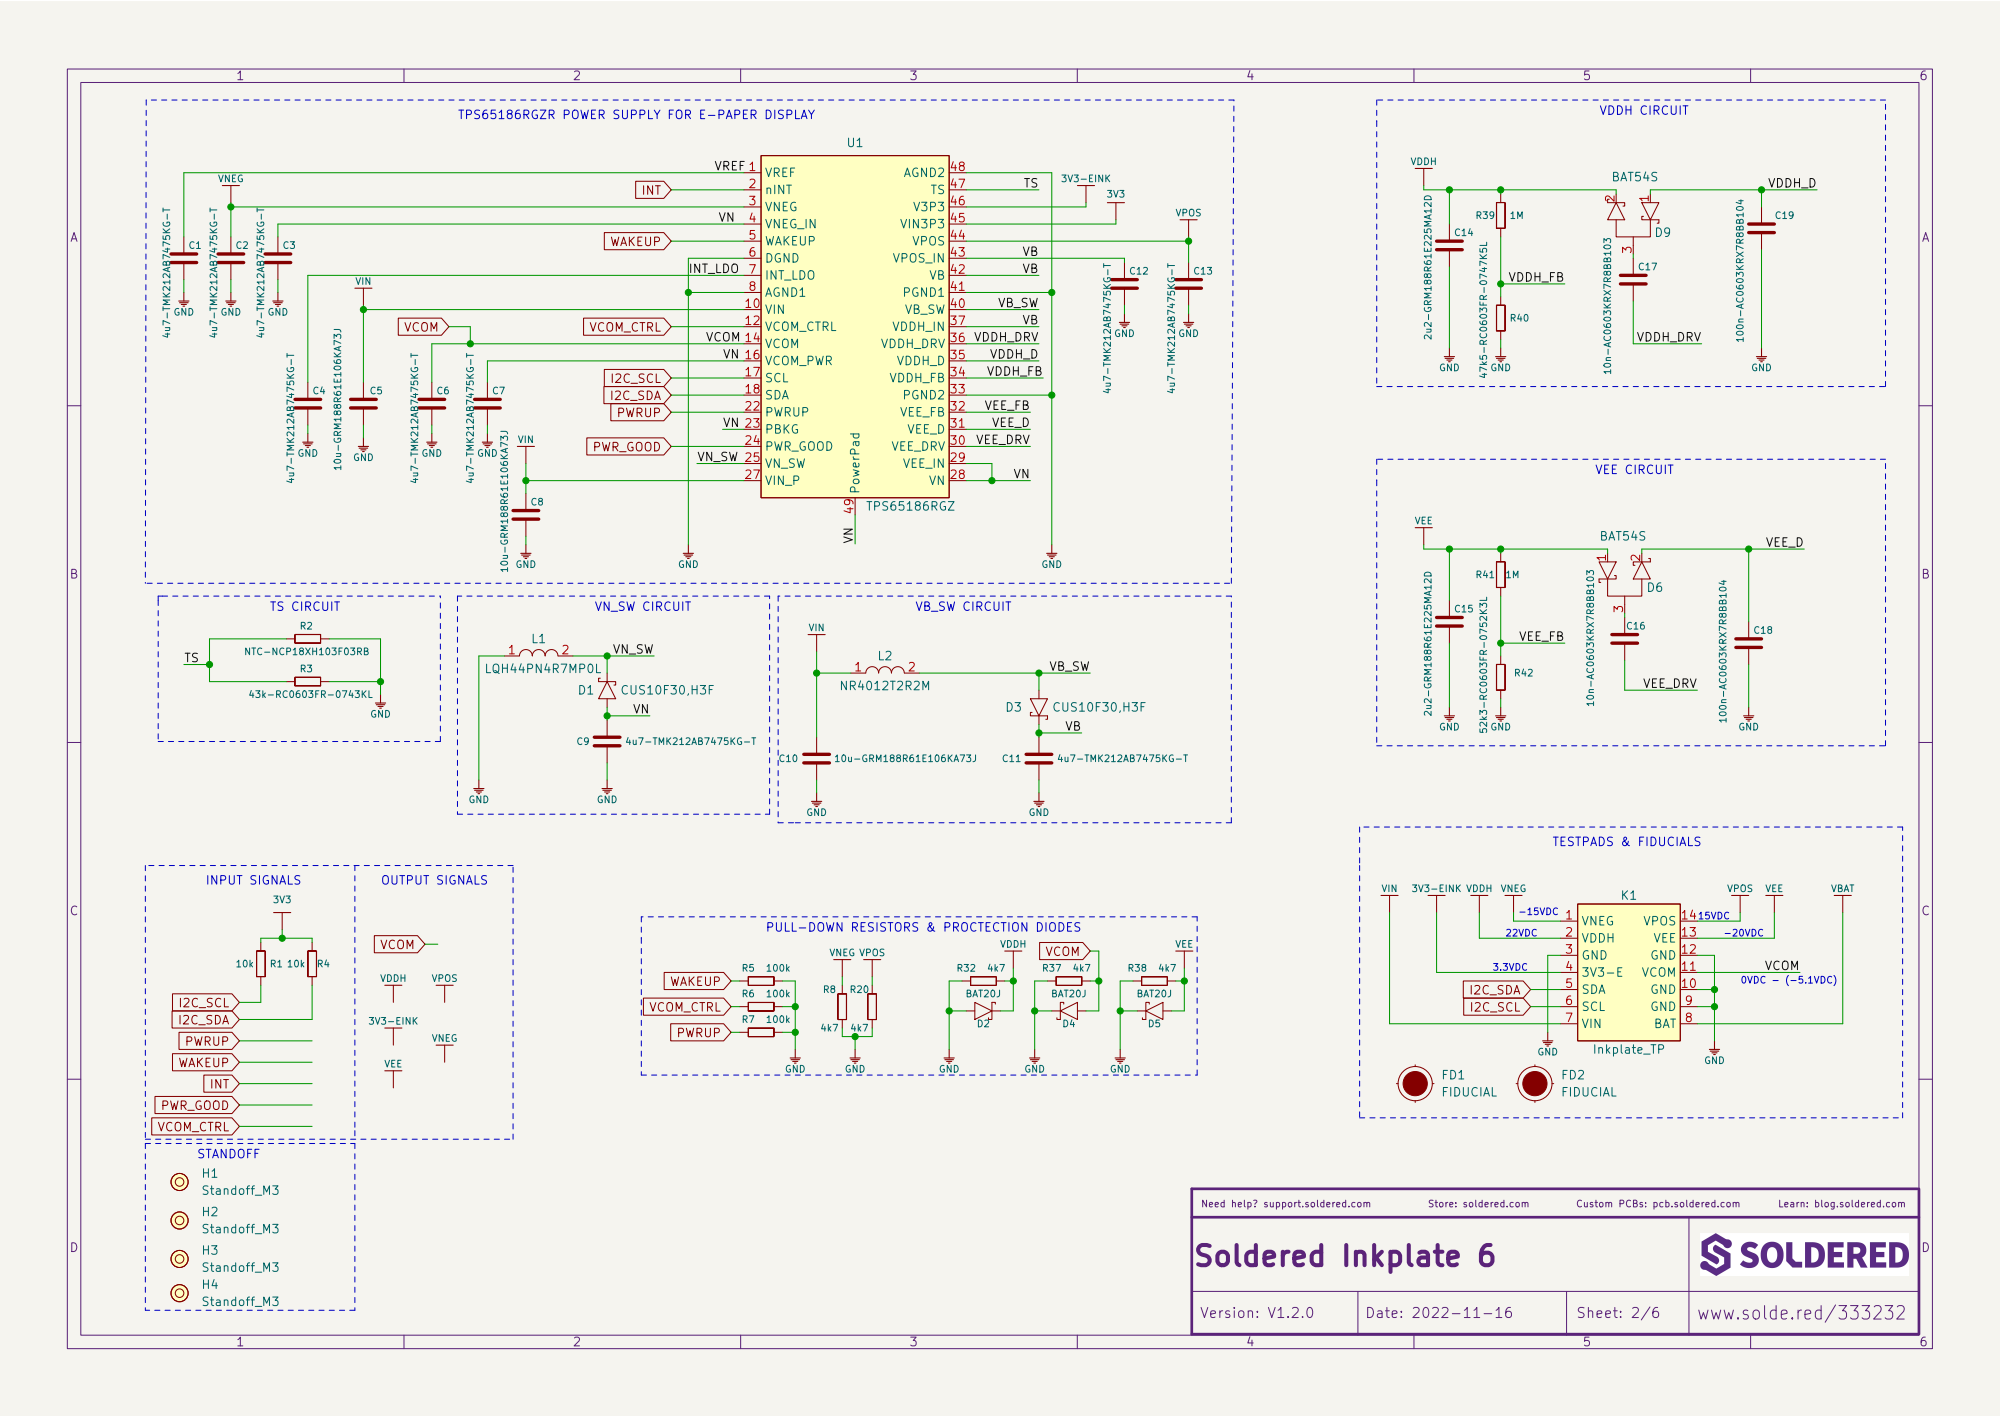
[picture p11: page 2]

TPS65186RGZR POWER SUPPLY FOR E-PAPER DISPLAY

VREF 1 VIN 10 VCOM_CTRL 12 VCOM 14 VCOM_PWR 16 SCL 17 SDA 18

VN | VDDH_D
VN VN_SW | VDDH_FB

0VDC - (-5.1VDC) PULL-DOWN RESISTORS & PROCTECTION DIODES OUTPUT SIGNALS

Learn: blog.soldered.com

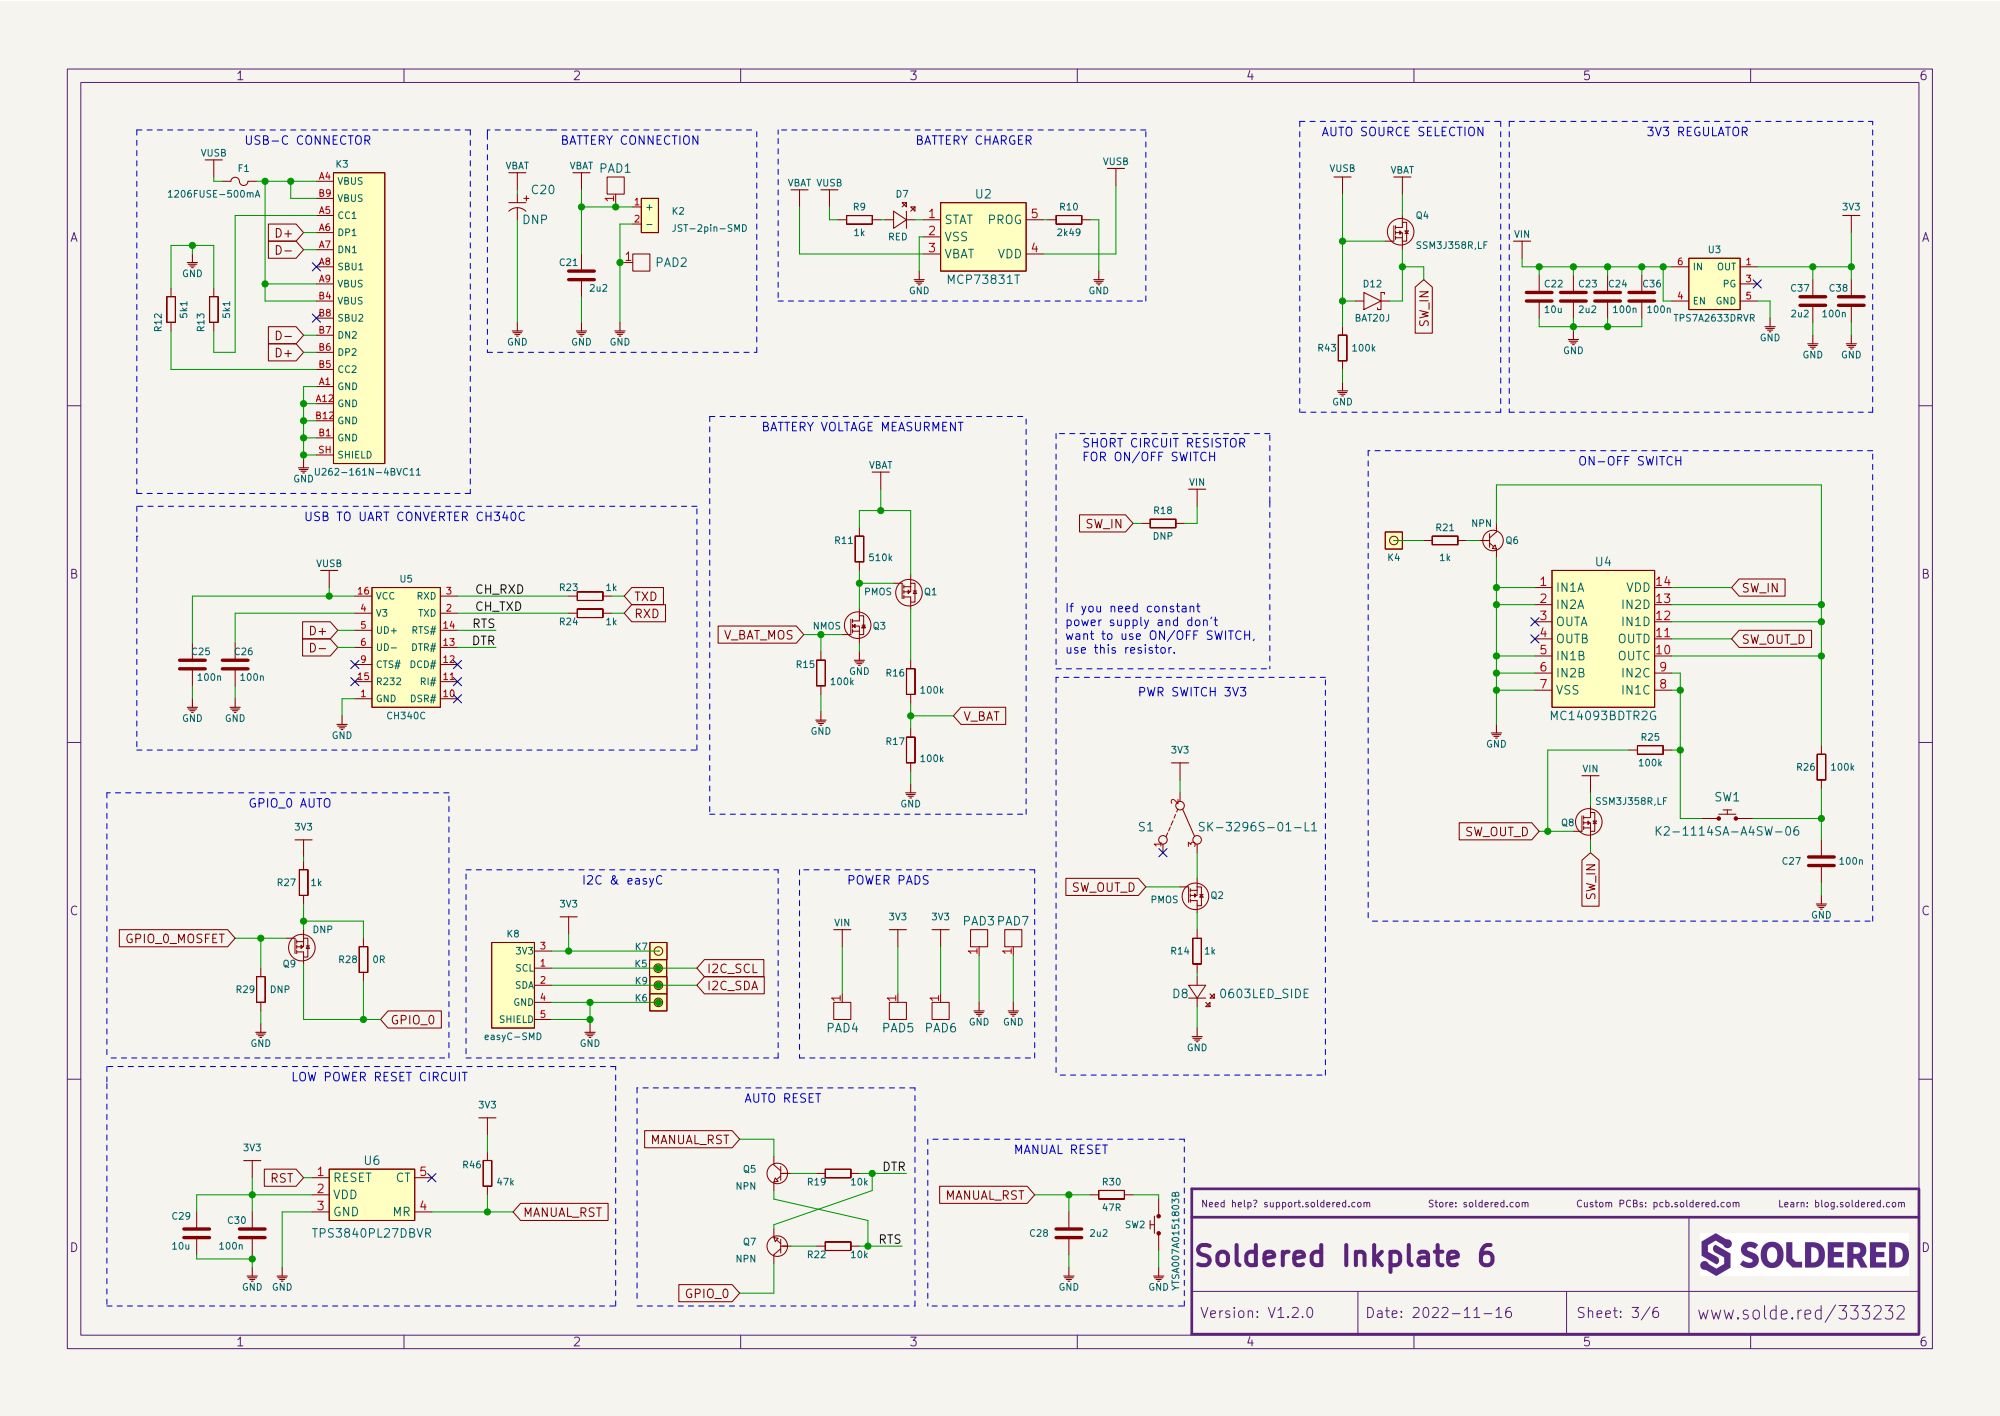
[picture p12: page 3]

BATTERY VOLTAGE MEASURMENT POWER PADS

power supply and don't want to use ON/OFF SWITCH, use this resistor. PWR SWITCH 3V3 SHORT CIRCUIT RESISTOR
FOR ON/OFF SWITCH

USB TO UART CONVERTER CH340C

If you need constant

1 PAD5 Q7 NPNQ5 NPN RESET R19 10k 1 VDD 2 GND 3 MR 4 CT 5 U6 TPS3840PL27DBVR
100n GND

LOW POWER RESET CIRCUIT

Learn: blog.soldered.com

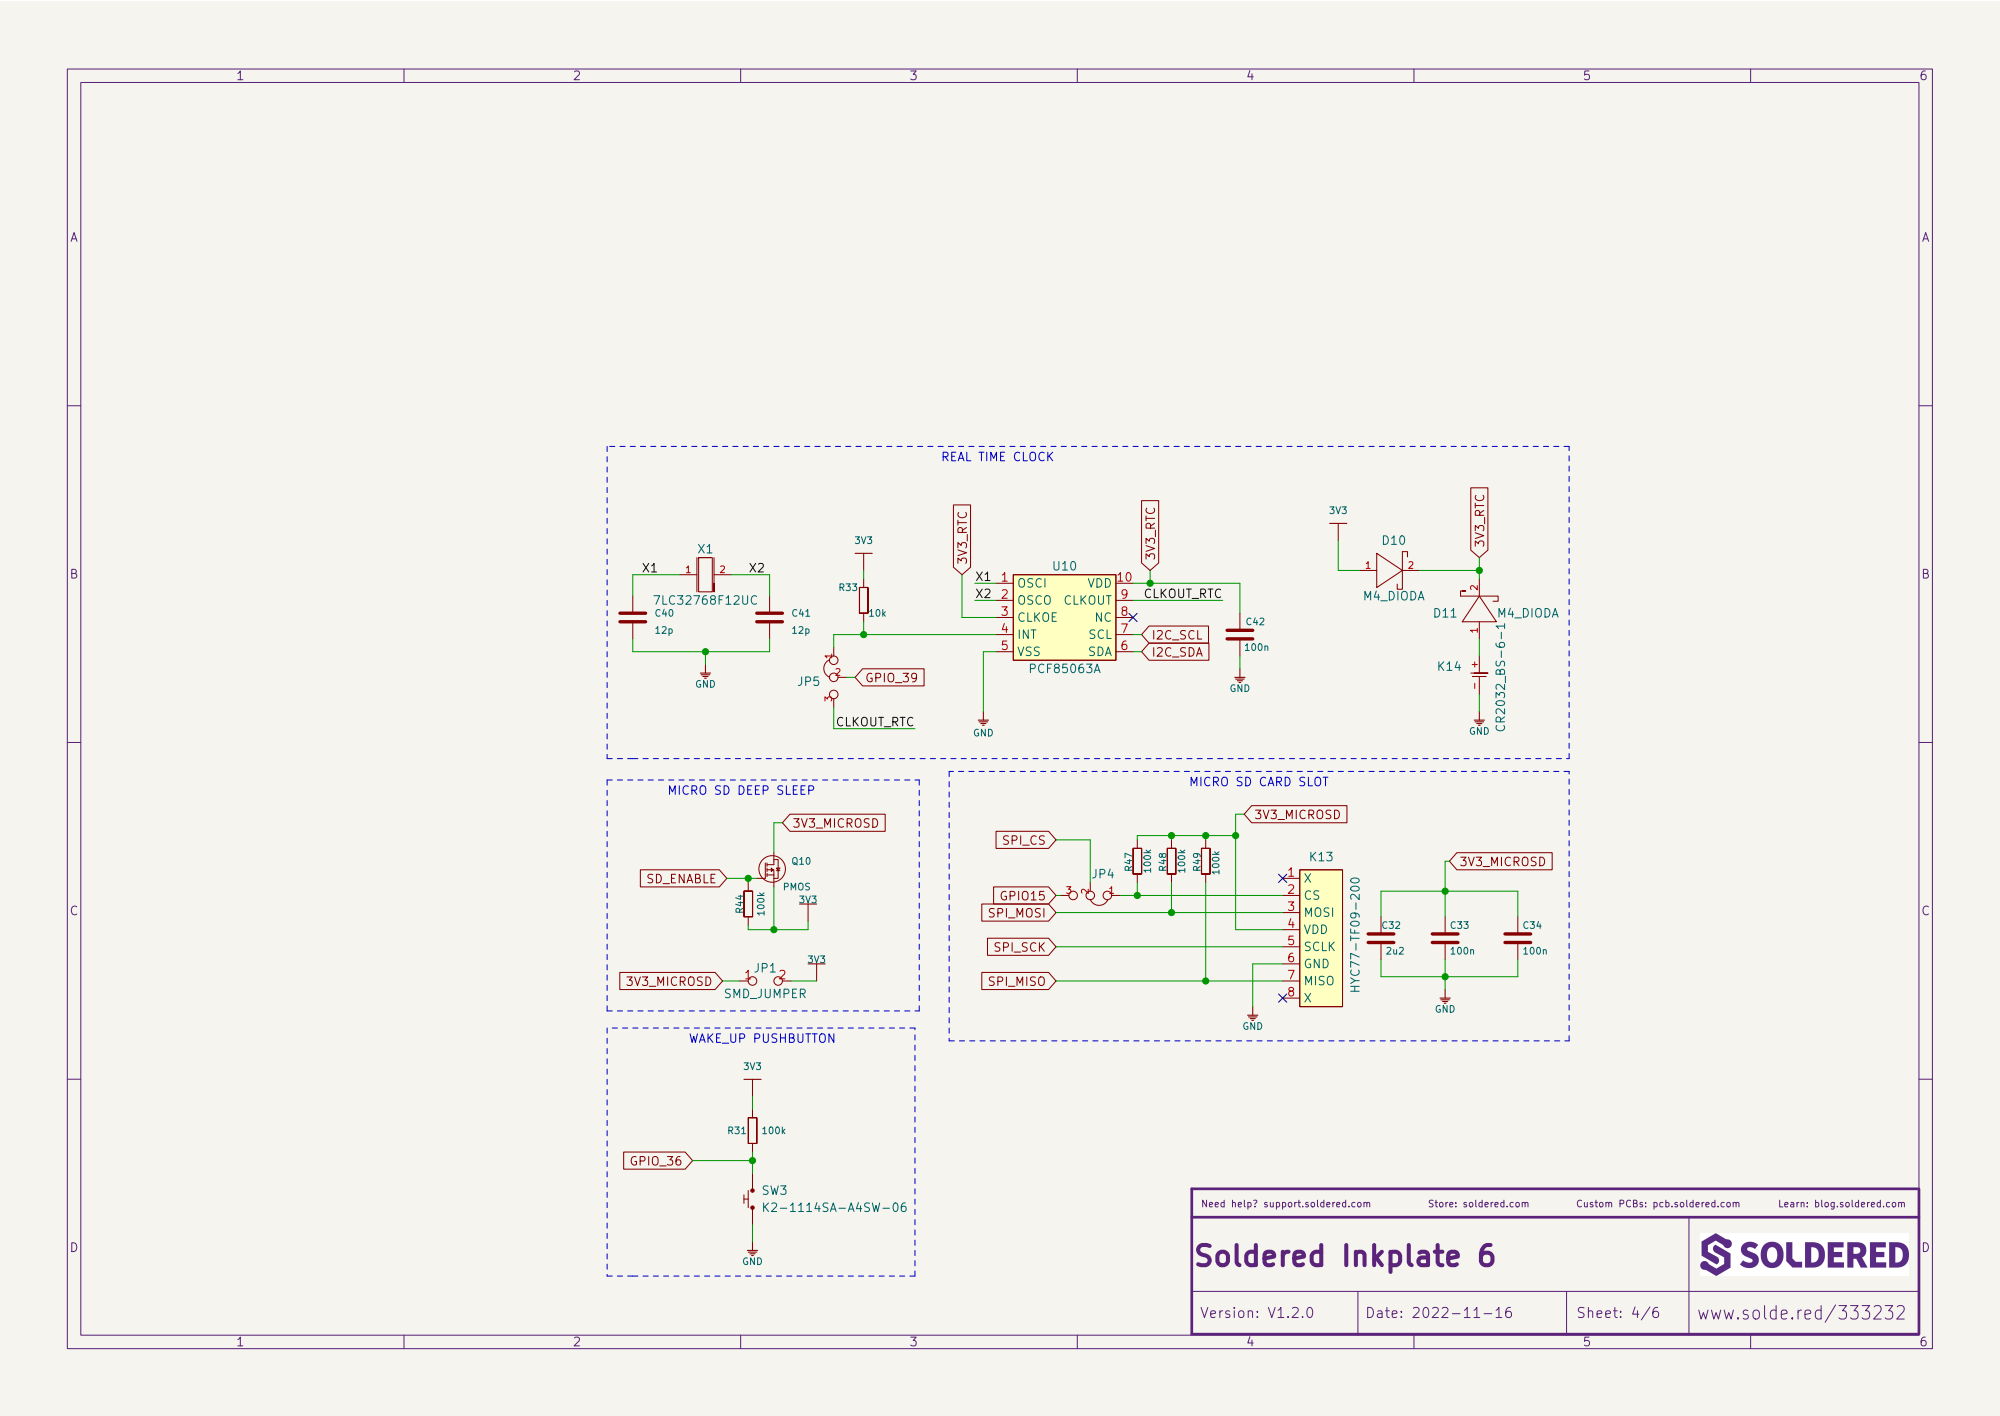
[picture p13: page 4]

Learn: blog.soldered.com

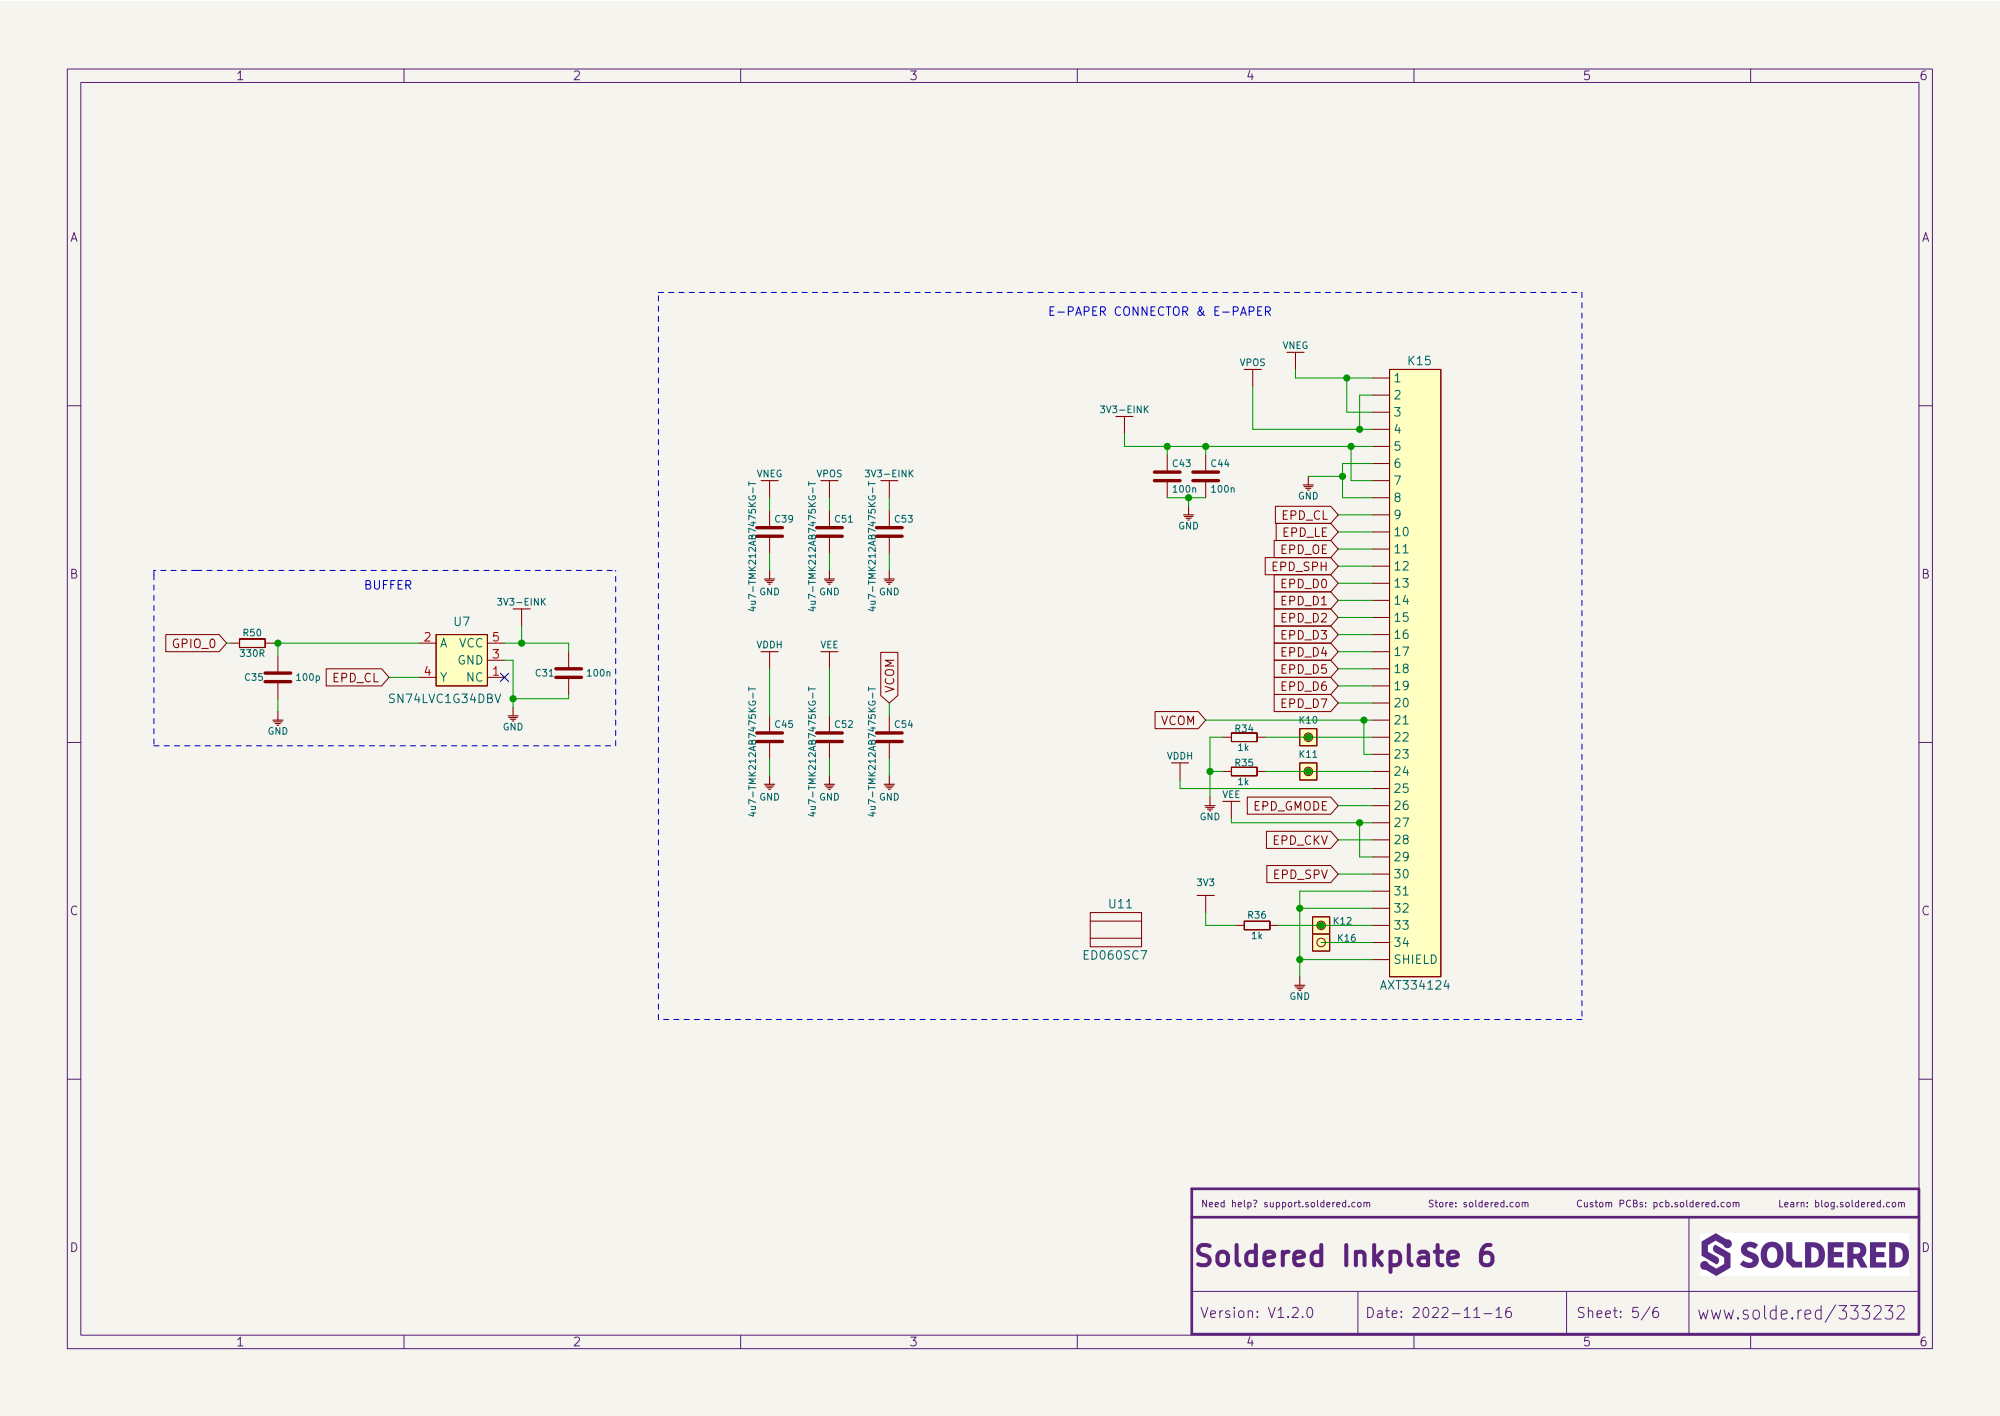
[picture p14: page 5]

Learn: blog.soldered.com

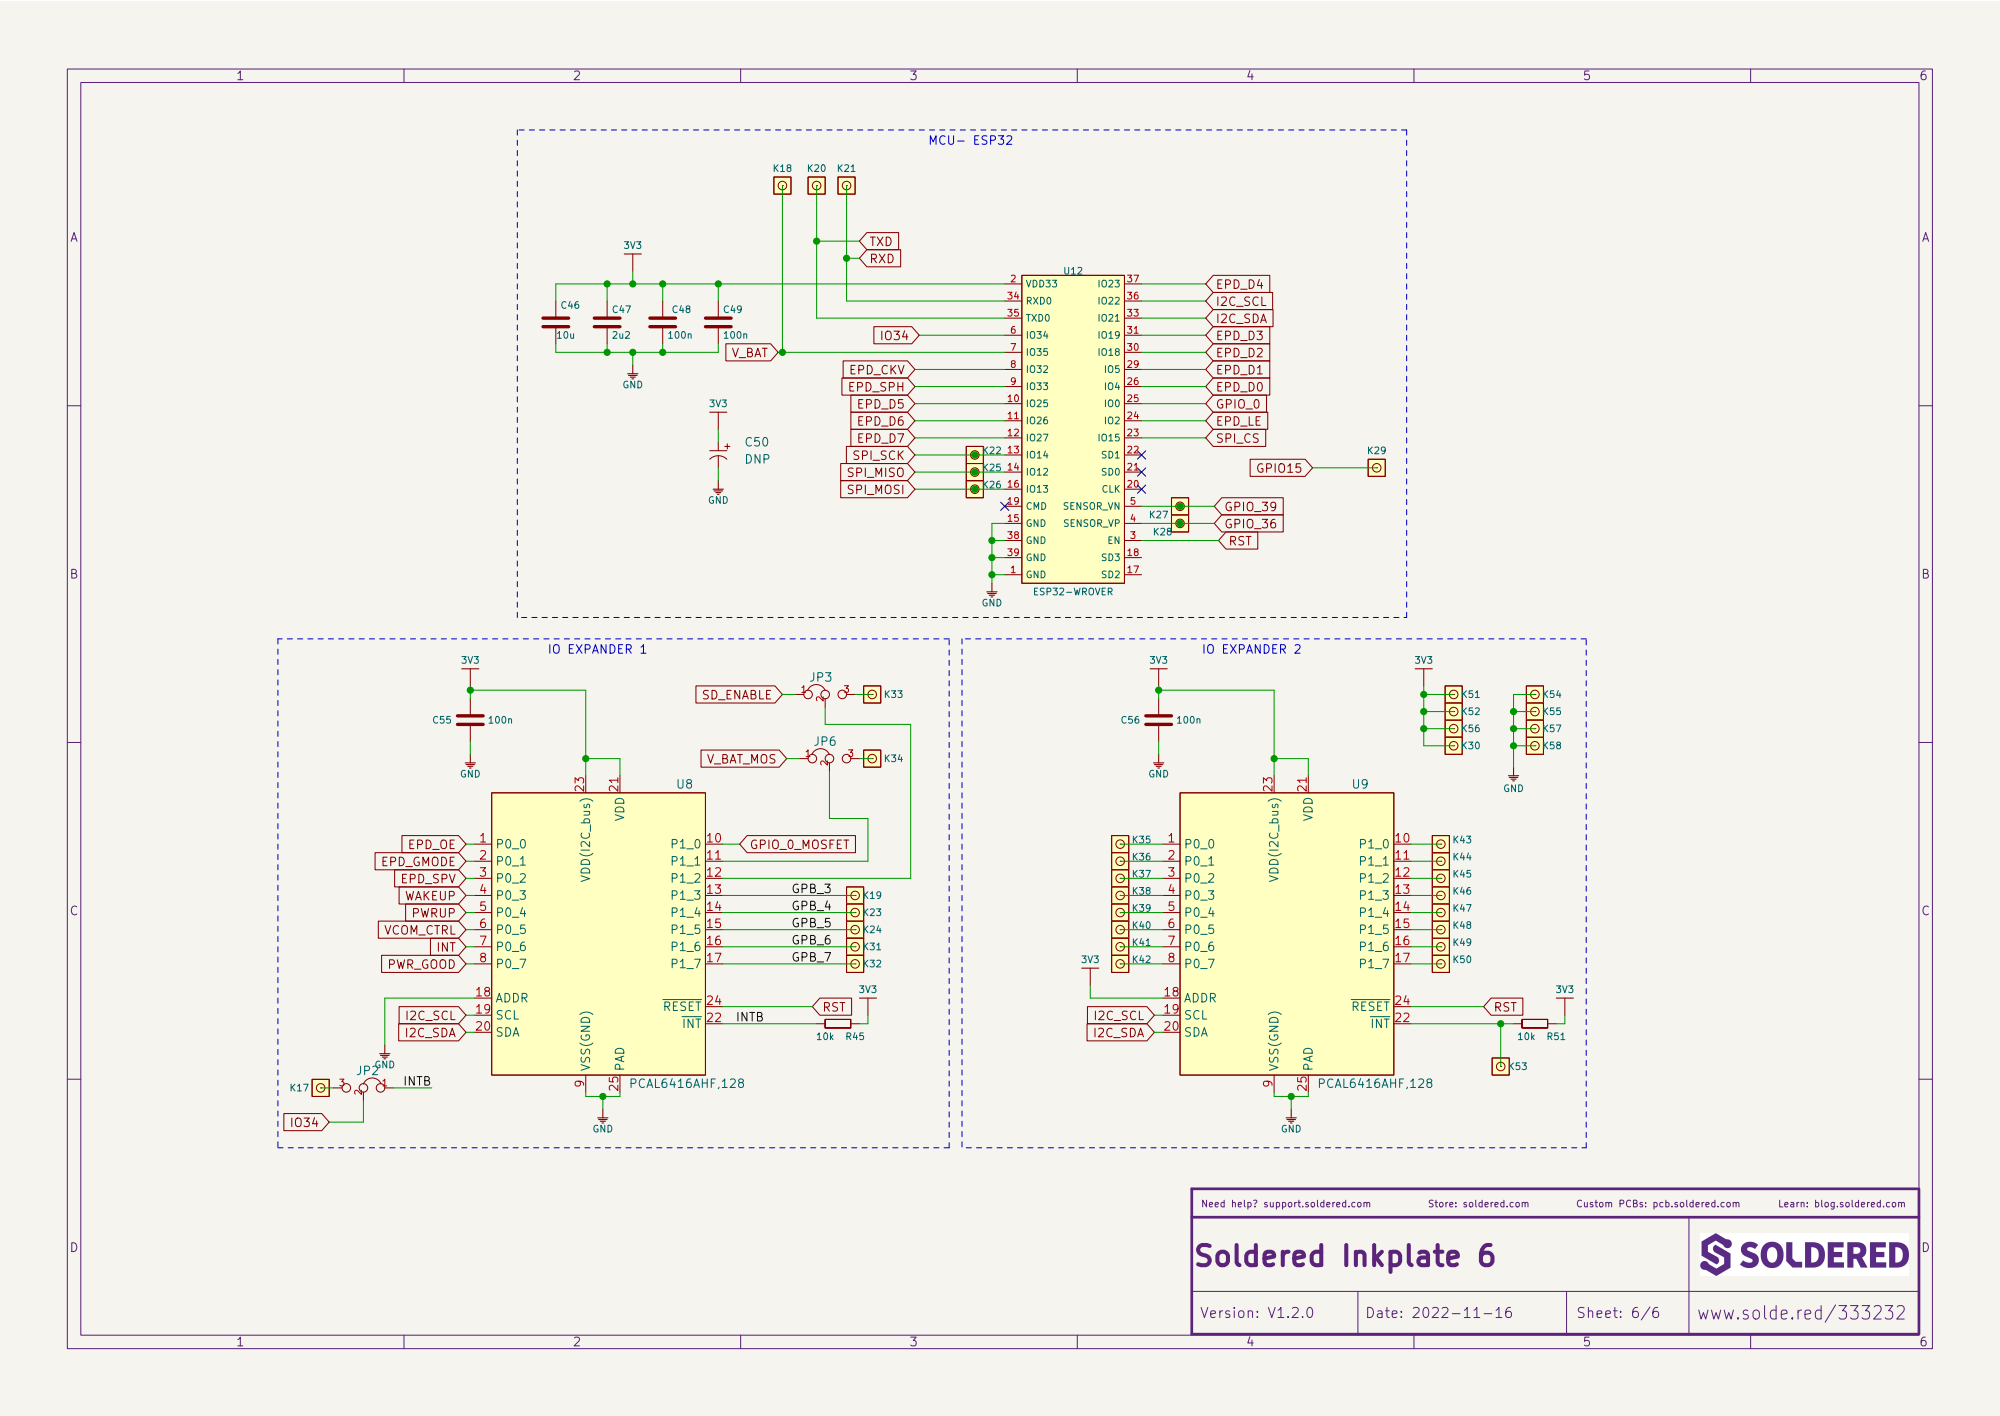
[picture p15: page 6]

Learn: blog.soldered.com
